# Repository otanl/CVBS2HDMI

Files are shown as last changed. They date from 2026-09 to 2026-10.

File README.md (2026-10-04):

# CVBS2HDMI — composite NTSC to HDMI on a Tang Nano 20K

English | [日本語](README.ja.md)

**v0.1**

> **Status.** What has been tested is the firmware together with the board as built, v0.1
> (tag `v0.1`). The board design now in `hardware/` is **v0.2, which has not been manufactured or
> tested**. If you make a board, either accept that, or use the v0.1 design from the tag.

CVBS2HDMI digitises composite NTSC video (CVBS) with an 8-bit ADC (AD9280), decodes it in colour on the
Tang Nano 20K's FPGA, and sends it to the on-board HDMI connector as 640×480p. There is no frame
buffer. Everything is built with an open-source toolchain (Yosys / nextpnr-himbaechel / Apicula /
openFPGALoader / Icarus Verilog); development was done on macOS.

## Features

- Colour NTSC decoding (240p and 480i) to 640×480p HDMI (DVI-compatible)
- 25.2 MSPS, one sample per clock, with no multipliers or ALU cells; the colour burst's phase
  is measured on every line with a CORDIC
- 240p, as most game consoles send it, holds still: the output frame switches between 524 and
  525 lines to match
- A broken or missing input is shown as noise, never as a black screen
- S2 zooms the picture 1.5 times and crops the border (a ring buffer of lines, no frame buffer)
- Eight glitch effects on the knobs of an M5Stack Unit 8Angle, each breaking a stage of the
  decoder itself
- Regression tests in simulation for every feature (`make test`)

Not supported: PAL, audio, black-level correction for 7.5 IRE setup.

## Hardware

- **Tang Nano 20K** (GW2AR-LV18QN88C8/I7)
- **Carrier board** (`tangADC`): an AD9280ARS and its input circuit, taking the Tang Nano 20K in
  a DIP-40 socket
  - Input: RCA → 75 Ω termination → ESD protection → 1 µF AC coupling → 20 Ω + 100 pF → AIN
  - AD9280: internal 2 V reference, single-ended input (0..2 V), clocked at 25.2 MHz by the FPGA
  - DC restoration is digital (black level measured on the front porch); the analog clamp is
    not used
  - Powered from the Tang Nano 20K's 3.3 V, with separate analog and digital rails through
    ferrite beads
- **Optional**: M5Stack Unit 8Angle (Grove J4/J5, I²C)

The carrier board's KiCad 10 project is in `hardware/`: schematic, PCB, and the JLCPCB
production files (BOM, placement, gerbers). They are at v0.2, the next revision, which has not
been manufactured; the board as built and measured is tag `v0.1`. `docs/pcb-respin.md` §4.6 and
§4.7 list the changes. Every part JLCPCB places is from its Basic or Preferred library.

Pin assignment (the single source is `constraints/tangnano20k_adc_probe.cst`):

| Signal | FPGA pin | | Signal | FPGA pin |
|---|---|---|---|---|
| `adc_clk` | 73 | | `adc_d[4]` | 29 |
| `adc_clamp` | 74 | | `adc_d[5]` | 30 |
| `adc_d[0]` | 27 | | `adc_d[6]` | 75 |
| `adc_d[1]` | 28 | | `adc_d[7]` | 77 |
| `adc_d[2]` | 72 | | `adc_otr` | 71 |
| `adc_d[3]` | 76 | | I²C SCL / SDA | 48 / 49 |

The data bus is not in physical pin order. The board's revision history, the pins that must not
be used, and the fixes planned for the next revision are in `docs/pcb-respin.md` (Japanese).

**Caution**: pin 3 of the Grove connectors is 5 V. A device that pulls I²C up to 5 V puts 5 V
on the FPGA's pins. The 8Angle pulls up to its own 3.3 V and is safe.

**Caution**: ADC bits 0, 1, 4 and 5 (pins 27..30) share an I/O bank with HDMI. Stock Apicula
packs those inputs as LVDS receivers, so every build must go through `scripts/gowin_pack_io.py`
(the Makefile does).

## Usage

### Installing the tools (once)

```sh
./scripts/setup-macos.sh
make check-tools
```

This installs the OSS CAD Suite into `.tools/oss-cad-suite`; your shell's PATH and macOS
settings are left alone.

### Building and loading

```sh
make ntsc                # build
make ntsc-program        # load into SRAM (lost at power-off)
make ntsc-flash          # write to flash (kept across power cycles)
```

`make program` loads not the HDMI decoder but the ADC probe used to bring up a board (see below).

### Buttons and LEDs

- **S1**: toggles the diagnostic view (waveform and bars). The black-and-white cells showing the
  ADC interface's state appear only at the bottom of this view.
- **S2**: toggles the 1.5× zoom, which scales up the middle of the picture and crops the border
  (for sources such as game consoles whose picture sits small inside a wide border). Both axes
  scale alike, so the aspect ratio is kept. After a switch the picture slides into place over
  about 1.5 seconds.
- **LEDs** (active low): 0 heartbeat, 1 PLL locked, 2 horizontal sync locked, 3 vertical sync
  seen, 4 and 5 the luma gain step

An input that cannot be synced (a broken signal, a wrong standard, an unplugged cable) does not
black out the screen: the signal is shown as it arrives, as noise, and a good signal is locked
again as soon as it returns. 240p (262 lines every field, 60.05 Hz), as most game consoles send
it, is shown by measuring the field length and switching the output frame between 525 and 524
lines.

### M5Stack Unit 8Angle (glitch effects)

Connect an M5Stack Unit 8Angle to Grove J4 or J5 and its eight knobs and switch are read
continuously over I²C (address 0x43, 100 kHz). Near the bottom of the S1 diagnostic view, each
knob is drawn as a cyan bar, the switch as a green block, and a red block shows while the unit
is not answering. `make sim-angle8` checks the reader against a model of the unit.

The eight knobs control **glitch effects**. They do not post-process the image; each one breaks
a stage of the decoder itself. A knob turned fully left is off, and with all knobs left the
picture is the clean one. The effects are enabled with the switch in the green position (as the
diagnostic view shows it).

Knobs 1..4 break **where lines go and their shape**, 5..8 break **colour**; each group is in the
order the signal passes through the decoder.

| Knob | What breaks |
|---|---|
| 1 | Sync slicing: dark parts of the picture read as sync, so the picture decides where lines start |
| 2 | Horizontal hold: real syncs are ignored and the line timing free-runs off frequency (sideways drift, diagonal tearing) |
| 3 | Line stretch: lines at random are stretched to twice the width or squeezed to half, leaving an older line behind |
| 4 | Line buffer: lines stop being updated, and old lines smear downwards |
| 5 | ADC bus faults: the faults this board really had, in order (pair misreads → stuck bits → crossed wiring) |
| 6 | Colour reference collapse: the burst is measured inside the picture and the oscillator drifts, so the hue jumps and rainbow stripes roll |
| 7 | Colour matrix overflow: the YUV→RGB gain is raised and the clipping removed, so bright and saturated parts fold into their complements (neon, solarised) |
| 8 | HDMI link failure: first the lanes skew, splitting red, green and blue sideways with a per-line shiver; past half way, blocks of a few lines lose a colour lane or misread it (inverted and so on). Worked out in the FPGA as the monitor would show it, so the link never drops |

`make sim-video-glitch` checks that each effect breaks the picture and that the picture is clean
again once the effect is removed. `make sim-link` checks, line by line, that the HDMI link
failure breaks the picture only in the ways it is allowed to.

### Sources with no sync step

A signal whose sync tip sits at blanking level (an early M5 setup, for example) needs a build
with different window positions. It is not switched automatically.

```sh
make ntsc-legacy
make ntsc-legacy-program
```

On a source with a sync step, the default (`LEGACY_TIMING=0`) measured 0.43% dropped rows and
colour on 120/120 frames, against 47.8% and 0/120 for `LEGACY_TIMING=1` (2026-09-24, same seed).

### Going back to a known-good version

The version verified on 2026-09-26 (tag `good-2026-09-26`) is kept as a bitstream,
`bitstreams/ntsc_good_2026-09-26.fs.gz`, so it can be written back whatever happens to the
sources or the toolchain.

```sh
make restore-flash       # write it to flash (kept across power cycles)
make restore-program     # load it into SRAM only (to try it)
git checkout good-2026-09-26   # the sources as they were
```

## Tests

```sh
make test                # everything (a few minutes)
make sim-video           # NTSC-J 75% bars, three fields, vertical interval included
make sim-zoom            # the 1.5× zoom (240p and interlaced, with a negative control)
make sim-video-glitch    # each glitch effect breaks the picture, and removing it restores it
make sim-link            # the HDMI link failure effect
make sim-hdmi            # TMDS encoding, line buffer races, start-up and video timing
```

`make test` includes negative controls: each bench also has to recognise a deliberately broken
setup as broken.

## Development and diagnostics

The decisions and measurements made during development are recorded in `CLAUDE.md`. When the
hardware behaves unexpectedly, search there first.

### Picture quality

```sh
make sim-reference       # every phase, ±100 ppm, half-wave burst, signal loss
make sim-tracking        # colour phase from the first line after 24 lines without burst
make sim-video-weak      # small sync amplitude
make sim-video-mono      # monochrome input with no burst
make sim-video-late      # recovery from a horizontal sync that arrives late
```

PNG captures of the HDMI output can be scored with the Python standard library and FFmpeg:

```sh
python3 scripts/video_quality.py 'build/cap*.png' --rows 20:350 --start 24 --bar-width 80
```

It reports, separately, rows in luma order, rows with a dark first bar, rows with colour, RGB
saturation, and row-to-row colour variation. The grey staircase in the bottom quarter is left out;
compare only captures of the same region and test pattern. The first capture after programming
is affected by the link and the vertical position re-acquiring, so always capture twice and score
the second, the same way for both sides of a comparison. Frames with no signal are counted too.
Bars in luma order do not prove that hue or amplitude is right.

With no UART, ADC values can be measured from the waveform view on HDMI:

```sh
make ntsc-scope-program             # starts in the full-range waveform and diagnostic view
# compare a phase: make ntsc-scope-program NTSC_SCOPE_PHASE=4
./scripts/live_capture.sh build/scope_new 120 8 --scope-mode 0 --phase 2
python3 scripts/scope_trace.py build/scope_new_012.png --trace-only --require-mode 0
# check the display path with a known ramp: make ntsc-scope-program NTSC_SCOPE_RAMP=2
make ntsc-program                   # back to the normal picture
```

To look at a signal that has no usable sync, capture raw ADC data without waiting for sync:

```sh
make ntsc-scope-program NTSC_SCOPE_RAMP=3 NTSC_SCOPE_FREERUN=1
./scripts/live_capture.sh build/raw_free_new 12 3 --scope-mode 3 --phase 2
python3 scripts/scope_trace.py build/raw_free_new_012.png --trace-only --require-mode 3
```

The normal capture waits for sync, and when none is found its buffer is never written, so zeros
that were never captured can be mistaken for measurements. `NTSC_SCOPE_FREERUN=1` captures every
66 ms or so regardless of sync, and the build gets its own name. `make sim-scope-freerun` checks
that all 2048 points are captured and re-captured with no sync, and that the sync-waiting mode
does not capture.

The waveform is drawn at 640×480 with three samples a pixel, and values are recovered from the
height of the red and white trace. The diagnostic build's vertical axis shows all 256 codes; to
read the S1 view of the normal build, pass `--legacy-scale` (there, codes above about 150 are
hidden behind the bars at the top). Ambiguous columns are dropped. This is an approximate
measurement from the screen, not a dump of every sample. Rows 200..207 of the diagnostic view
carry the mode, the ADC phase and a frame counter. `live_capture.sh` always captures at least
twice and checks the mode, the phase and that the counter advances; each time it sets aside the
first 120 frames as warm-up and measures the requested number after them. It never filters out
bad frames from the measured run. Each attempt is kept in its own folder and existing images are
never overwritten (use a new prefix). On the normal picture only pixel changes are checked:
without the diagnostic counter, a still picture cannot be told from a frozen capture, nor the
loaded bitstream identified. Amplitudes of oscillating parts are not validated; use
`--trace-only`, and do not use these readings to set colour gain.

### Recording the input and replaying it in simulation

The waveform view shows one sample in three; this records 32768 consecutive raw ADC samples
(about 20 lines) exactly, without the UART.

```sh
make ntsc-tape-program                                  # record once, freeze, show as grey cells
python3 scripts/live_capture.py build/tape 12 8
python3 scripts/tape_decode.py build/tape.hex build/tape_0*.png   # vote across 12 frames
python3 scripts/tape_trim.py build/tape.hex sim/my_tape.hex 18    # cut to an even number of lines
./scripts/tool iverilog -g2012 -s replay_tb -o build/replay_tb \
    src/ntsc_capture.v src/adc_front.v src/sync_lpf.v src/burst_nco.v src/cordic_atan.v \
    src/chroma_sincos.v sim/gowin_prim_sim.v sim/replay_tb.v
./scripts/tool vvp build/replay_tb +stim=sim/my_tape.hex +nsamp=<samples> +lines=400 +out=build/replay.txt
python3 scripts/replay_quality.py build/replay.txt --png build/replay.png  # same scale as the board
python3 scripts/tape_reference.py sim/my_tape.hex                          # floating-point reference decode
```

`replay_quality.py --frames 'build/cap_*.png'` scores captures from the board on the same scale.
`make sim-tape` checks the recording display and its decoder end to end against a known memory
image.

**With the M5 as the source, correctly decoded bars are not in luma order** (the M5 itself sends
yellow < cyan, green < magenta, red < blue). To evaluate with the M5, compare `replay_quality.py`'s
hue error and line-to-line variation with `tape_reference.py`'s values instead of
`video_quality.py`'s "correct rows".

## ADC probe (for bringing up a board, 27 MSPS)

A separate design for the first check on a new board: that the ADC's data is captured correctly.

Measured in step 1:

```
ADC ph=2 tog=FF min=96 max=255 thr=115 ln=1716 lmin=1715 lmax=1717 ok=15734 lns=15734 vs=60 otr=0 lk=1
```

A raw waveform (taken with `make autodump-program`, saved as `sim/ntsc_line_capture.hex`):

| Quantity | Measured | NTSC | Error |
| --- | --- | --- | --- |
| Sync tip | code 98 (±1) | — | — |
| Sync width | 4.59 us | 4.70 us | -2.3% |
| Blanking | code 133.9 | — | — |
| Sync to blanking | 282 mV | 286 mV | **-1.3%** |
| Burst start | 5.19 us after the sync edge | 5.3 us | — |
| Burst length | 2.52 us / **9.02 cycles** | 2.51 us / 9 cycles | **+0.2%** |
| Line period | **1716** samples | 1716.05 | — |

Counting exactly nine burst cycles shows that the sample clock and the subcarrier are in the right
time relation, and an amplitude error of -1.3% shows that the gain is right.

### Simulating

A synthetic NTSC signal goes through a behavioural model of the AD9280 and the line period is
measured.

```sh
make sim           # positive: must measure ln=1716
make sim-badphase  # negative: a wrong sampling phase must be reported as broken
```

The negative case exists to show that `ln=1716` is not a value that comes out whatever goes in.

### Loading it and measuring

```sh
make program   # load into SRAM (lost at power-off)
make monitor   # read the report
```

One line a second at 115200 8N1:

```
ADC ph=2 tog=FF min=79 max=205 thr=94 ln=1716 lmin=1716 lmax=1717 ok=15720 lns=15734 vs=60 otr=0
```

| Field | Meaning | Healthy value |
| --- | --- | --- |
| `ph` | sampling phase; 0..3 = 0 / 9.3 / 18.5 / 27.8 ns after the adc_clk rising edge | `2` |
| `tog` | OR of the bits that changed during the window | `FF` |
| `min` | lowest code → the sync tip level | about 70..90 |
| `max` | highest code → peak white | about 190..215 |
| `thr` | the sync slicing threshold actually used | min + a few tens |
| `ln` | the latest line period (samples) | **1716** |
| `lmin` / `lmax` | range of accepted line periods | 1716..1717 |
| `ok` | lines whose period is within 1700..1732 | about `lns` |
| `lns` | accepted lines | about 15734 |
| `vs` | vertical syncs detected | about 60 |
| `otr` | samples the AD9280 flagged as over range | `0` |

**`ln=1716` is the decisive one.** One NTSC line (15734.264 Hz) sampled at 27 MHz is

```
27e6 / 15734.264 = 1716.05 samples
```

so a steady 1716 proves at once that **the ADC clock, the data bus's bit order and the sampling
phase are all right**. No other single figure says that much.

#### Buttons (probe)

* **S2 (pin 87)**: advance the sampling phase by one. If `ln` does not appear, try all four.
* **S1 (pin 88)**: dump 2048 raw samples from a sync edge in hex, for checking the bit order by
  eye. The sync tip (a run of low values), then the back porch, then the picture should be
  visible.

#### Diagnostic LEDs (active low, probe)

| LED | Meaning |
| --- | --- |
| 0 | heartbeat (the design is running) |
| 1 | PLL locked |
| 2 | line period in range |
| 3 | vertical sync detected |
| 4 | over range detected (input too large) |
| 5 | a data bit never changes (bad wiring and so on) |

### The analog clamp is off by default

The AD9280's clamp (CLAMP/CLAMPIN) is **not used**: on this board it does more harm than good.
C2 at 1 µF is larger than the AD9280's clamp amplifier is designed for, so each pulse leaves a
transient longer than a line, which spoils the next sync edge. Measured:

| Clamp | Result |
| --- | --- |
| off (default) | `ok = lns = 15734`, `vs=60`, `ln=1716`, perfect |
| gated on sync lock | about 72% good lines, lock oscillating at 1 Hz, `vs` erratic |

Without the clamp the input still biases itself inside the conversion range (sync tip at 98,
white at about 225, 30 codes below 255). The decoder measures the porch and restores DC
digitally. The sync tip is not the black level, so do not subtract it from the picture.

`make clampgated-program` brings the clamp back for experiments.

### Builds for isolating faults

For suspecting the analog side. The RTL is the same; only a constraint or a parameter differs.

```sh
make pullup-program    # weak pull-ups on the ADC inputs; min=max=255 means the ADC is not driving the bus
make clampon-program   # CLAMP held on: AIN pinned to CLAMPIN, measurable with no video
make clampoff-program  # CLAMP held off (for comparison)
make clkhigh-program   # adc_clk held at 3.3 V → TP4 should read about 3.3 V
make clklow-program    # adc_clk held at 0 V → TP4 should read about 0 V
make clkslow-program   # adc_clk at about 1 Hz → TP4 swings 0 ↔ 3.3 V on a meter
make program           # back to normal
```

`clk=` at the end of the report shows which clock mode the loaded bitstream has.

#### The pull test: finding a floating pin without touching the board

The most effective technique of the bring-up. Build the same design three ways, with no pull,
pull-up and pull-down, and compare the reported codes in binary. **A ~50 kΩ internal pull cannot
move a pin the ADC is really driving.** A bit that follows the pull is an open joint; a bit that
resists it is connected, one pin at a time.

```sh
make program && make monitor          # no pull
make pullup-program && make monitor   # pull-up
make pulldown-program && make monitor # pull-down
```

**The trap**: a test point measures the net, not the pin. TP4 shows a healthy clock even if the
AD9280's pin 15 is lifted, and FB2 shows 3.3 V even if pin 2 is. The pull test gets round this
electrically for every pin the FPGA can read.

If `min`/`max` stay at 0 with `clampon`, the cause is not the video signal but the ADC's
conversion, its reference or the clamp circuit. If the bus does not move with `clkslow` either,
the ADC is not responding to its clock.

#### AVDD and DRVDD come from different pins

Easy to miss: the AD9280's analog and digital supplies come from **different pins of the Tang
Nano**.

```
Tang Nano DIP pad 19 → +3V3 → FB1 → +3V3A → U1 pin 28 AVDD
Tang Nano DIP pad 25 →        FB2 → +3V3D → U1 pin 2  DRVDD
```

So **a healthy TP2 (VREF) does not prove that DRVDD is there**: VREF depends on AVDD alone.
Without DRVDD the digital outputs are never driven and the bus is dead. On the v0.1 board FB1 and
FB2 are leaded parts, easy to probe at both ends. (The next revision uses 0805 chip beads; probe
TP5 and TP6 on the ADC side and the module's 3V3 pins on the other.)

## HDMI output pitfalls

**Never put `DRIVE=` or `BANK_VCCIO=` on an LVDS25 constraint.** Sipeed's `.cst` for Gowin EDA
carries `DRIVE=3.5 BANK_VCCIO=3.3`; brought into the open-source flow, it builds, meets timing,
and produces a link **no sink locks to**, with no warning. Apicula's own
`examples/tangnano20k.cst` uses only `IO_TYPE=LVDS25 PULL_MODE=NONE`.

**The 20K's HDMI pins are true LVDS.** The 9K's are emulated, so `ELVDS_OBUF`/`LVDS25E` ported
as-is is rejected outright by Apicula. Use `TLVDS_OBUF`/`LVDS25`, with P on the pair's IOBA pin
and N on its IOBB pin (33/34, 35/36, 37/38, 39/40).

**Pass the pixel clock to `--freq`.** nextpnr applies `--freq` to every clock it does not
otherwise know, so passing the serial clock (135) fails the TMDS encoder's combinational path on
a timing violation that does not exist.

### When nothing comes out, compare with a known-good bitstream

Faster than reasoning. Load Sipeed's prebuilt `.fs` (fetched with `gh`) and you know at once
whether the board, cable and sink are fine. Build Apicula's `examples/DVI` with the same flow and
you also know that the open-source toolchain can drive this board's TLVDS; what is left is the
difference from your own sources.

## Common problems

* **The report is garbled**: macOS resets a `/dev/cu.*` port to 9600 baud when its last
  descriptor closes, so `stty -f PORT 115200` followed by `cat PORT` loses the setting.
  `make monitor` (`scripts/monitor.py`) sets the speed on the descriptor it reads from.
* **The board is not found**: use a USB-C cable that carries data, and connect directly, without
  a hub.
* **`unable to open ftdi device`**: close anything using the board's USB device (a serial
  monitor, for instance) and reconnect.
* **Starting over**: `make clean`, then `make build`.

## License

MIT License. See `LICENSE`.

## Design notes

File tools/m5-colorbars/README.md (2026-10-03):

# m5-colorbars — NTSC colour bar generator for decoder calibration

Turns an M5Stack ATOM (ESP32-PICO-D4) with the RCA unit into a composite
colour bar source, so the CVBS2HDMI decoder can be checked against known values
instead of by eye.

Output is on **G26** (DAC channel 2), which is where the M5Stack RCA unit sits.
LovyanGFX's `Panel_CVBS` generates the signal; ESP32-S2/S3/C3 are not
supported by it, but the ATOM's ESP32-PICO-D4 is.

Pattern: 75% colour bars (white, yellow, cyan, green, magenta, red, blue,
black) across the top three quarters, and a 16-step grey staircase along the
bottom for checking luma gain and linearity separately from chroma.

## Build and flash

```sh
. ~/esp/esp-idf/export.sh
cd tools/m5-colorbars
idf.py set-target esp32
idf.py build
idf.py -p /dev/cu.usbserial-XXXXXXXX flash
```

The ATOM enumerates as a CH9102 bridge (`Hades2001 / M5stack` in `ioreg`), so
its port is *not* one of the Tang's two `usbserial-2025...` nodes. Pass it
explicitly — several of this project's scripts pick the last matching port and
will otherwise grab the wrong one.

## Signal type

`USE_NTSC_J` in `main/main.cpp` selects between NTSC-J (0 IRE setup, black
equals blanking) and NTSC (7.5 IRE setup). It defaults to NTSC-J because it
keeps level arithmetic simple when calibrating, and because it is what
Japanese equipment expects.

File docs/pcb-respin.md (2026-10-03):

# tangADC 基板（CVBS2HDMIのキャリア基板） 再設計 指示書

2026-09-15 時点。現行基板で見つかった問題と、次の版で必ず守る事項。

**状況（2026-10-03、v0.1）**：2章のピン変更は改版済みで、2026-09-24に実機で検証しました。
3章は、その後の実測にもとづいて書き直しています。

**次の改版（v0.2）**：3.2 と 4.1〜4.3 は 2026-10-03 に `hardware/` の設計データへ反映しました。
**まだ製造していません。** 実物があるのは v0.1 だけで、v0.1 の設計データと製造ファイルはタグ
`v0.1` にあります。`hardware/` にあるのは v0.2 の設計データと製造ファイルです。反映した内容は
4.6、製造ファイルについては 4.7 にまとめています。

---

## 1. 今回の失敗と、その本質

**ADCのデータ3本がFPGAに届いていません。** `adc_d[2]`(FPGAピン42)、
`adc_d[3]`(41)、`adc_d[6]`(31)。8ビットのうち実質24階調(256階調中)しか
使えておらず、映像の上位3バーが同じ値に潰れ、色も行ごとに揺れます。

**原因は部品でも実装でもありません。** 以下はすべて測定で除外済みです。

| 疑い | 検証方法 | 結果 |
|---|---|---|
| 半田の開放 | 配置固定のプルテスト(`scripts/scope_pull_variant.py`) | どのビットもプルに追随せず＝開放ではない |
| GNDへの短絡 | テスターで対地抵抗 | 130 kΩ、正常ビット(D5)と同値 |
| AD9280の故障 | **新品の基板＋新品のICで再現** | 同じ3ビットが死ぬ |
| 読み出し経路 | 既知の鋸波を緩衝域に書いて読み返す | 241/256値、全列が誤差1以内で線形 |
| 信号源 | スタビライザー挿入で信号を変更 | 帯状化は不変 |
| 標本化位相 | 5位相すべて | すべて同じ |
| ADCクロックのデューティ | 40% / 60% | 60%はむしろ悪化 |
| IO規格 | LVCMOS33 / 18 / 25 / 12 | すべて同一 |

**残るのはピンの選択です。** そして本質はこうです。

> **ピンが使えるかどうかを、資料を読んで判断した。実測しなかった。**

CLAUDE.md には当時から次の警告が書かれていました。

> ピン27–31 / 41 / 42 の実際のバンクVCCIOをSipeedの回路図で確認してから
> `LVCMOS33` を信用すること。入力バスのバンク電圧が違うと、**無言でデータが化ける**。

この警告を実行しなかったことが、基板一枚分の損失になりました。

---

## 2. 次の版で必ず守ること

### 2.1 ピンは発注前に実測する（最重要）

推測も資料も信用しません。**手元のTang Nanoで実際に試験します。**

```sh
# 候補ピンを pin_probe[7:0] に割り当てた .cst を作り、
# プルアップ版とプルダウン版をそれぞれ書き込んで画面のセルを読む
make ntsc            # PROBE_ON=1 でビルドしたものを使う
```

判定は単純です。

- **プルアップで1、プルダウンで0を返すピン → 自由。使える**
- **どちらかに追随しないピン → 何かが繋がっている。使わない**

死んだ3本は、まさに後者の挙動でした。理由が分からなくても、**この試験だけで
除外できます**。

さらに強い確認として、駆動して読み返す試験(`PIN_TEST=1`)もあります。
**必ず陽性対照(`PIN_TEST=2`、期待値を反転)と対で実行してください。**
比較が走っていなければ、どちらも「異常なし」に見えます。

### 2.2 ピンの第二機能（Tang Nano 20K 回路図 v1.3 より）

**この表を最初に見てください。** 今回の失敗も、次に起こりうる失敗も、ここに
書いてあります。

**設定用 — 絶対に使わない。** 電源投入時にフラッシュからビットストリームを
読むのに使われます。ADCの出力を繋ぐと起動を妨害します。

| ピン | 機能 |
|---|---|
| 5, 6, 7, 8 | TMS, TCK, TDI, TDO（JTAG。書き込みに必須） |
| 9 | RECONFIG_N |
| 52, 53 | SCLK, DOUT/WE_N |
| 54, 55, 56, 57 | DIN/CLKHOLD_N, SSPI_CS_N/D0, SO/D1, FASTRD_N/D3 |
| 59, 60, 61, 62 | MCLK/D4, MCS_N/D5, MO/D6, MI/D7 |
| 87, 88 | MODE1, MODE0（起動モード） |

**クロック / PLL — 避けるのが無難。** I/Oとしては使えますが、専用配線が
あるので他用途に取っておく価値があります。

| ピン | 機能 |
|---|---|
| 4 | LPLL1_T_in（本設計の27 MHz入力） |
| 10, 11 | GCLKT_6, GCLKC_6 |
| 13, 15, 16 | LPLL2_T_in, LPLL2_T_fb, LPLL2_C_fb |
| 35, 36 | GCLKT_4, GCLKC_4（本設計のTMDS） |
| 51, 63 | RPLL2_T_in, GCLKT_3 |
| 76, 77 | GCLKC_1, GCLKT_1 |
| 79, 80 | GCLKT_0, GCLKC_0 |

**第二機能を持たない素のI/O** — ここから選びます。

```
17 18 19 20 25 26 27 28 29 30 31 32 33 34 37 38 39 40 41 42
48 49 69 70 71 72 73 74 75 81 82 83 84 85 86
```

### 2.2.1 Tang基板上の接続と実測結果

素のI/Oでも、Tangの基板上で何かに繋がっていれば使えません。**実測が要ります。**

| ピン | Tang上の信号 | 実測 |
|---|---|---|
| 27, 28, 29, 30 | LCD_B7 / B6 / B5 / B4 | 現行で正常動作 |
| **31, 41, 42** | LCD_B3, LCD_R4, LCD_R3 | **低く固定。今回の原因** |
| **32** | LCD_G7 | **高く固定** |
| 25, 26 | LCD_HS / VS | 低く固定 / 不安定 |
| **48, 49** | LCD_DE, LCD_BL | **自由（駆動＋読み返しで確認）** |
| 17〜20 | LED0〜5 | LEDと共用 |
| 69, 70 | UART TX / RX | BL616経由のシリアル |
| 71, 73, 74 | HSPI_DIN0 / DIN2 / DIN3 | 現行で正常動作（otr / clk / clamp） |
| **72, 75** | HSPI_DIN1, HSPI_DIR | **自由** |
| 81〜86 | SDIO ほか | 固定または不安定 |

同じLCDコネクタの信号線でも一部だけが固定されています。回路図に
`LCD_INIT0`〜`LCD_INIT3` というパネル種別識別らしき信号がありますが、
**原因は未確定です。理由が分からなくても実測で除外できます。**

### 2.2.2 推奨するピン割り当て

**素のI/Oで、かつ実測で確認済みのものだけ**を使います。現行から変わるのは
データ4本だけです。

**以下が実際に製造し、2026-09-24に実機で検証した割り当てです。** 動いている
5本はそのままにして、死んでいた3本だけを動かしました。基板の改版量が最小で
済み、既知良好な配線に手を入れずに済みます。

| 信号 | 旧 | **採用** | DIPパッド | 根拠 |
|---|---|---|---|---|
| adc_d[0] | 27 | 27 | 8 | 現行で正常動作 |
| adc_d[1] | 28 | 28 | 9 | 現行で正常動作 |
| adc_d[2] | 42 ✗ | **72** | **24** | 実測で自由（HSPI_DIN1） |
| adc_d[3] | 41 ✗ | **76** | **38** | 実測で自由（GCLKC_1） |
| adc_d[4] | 29 | 29 | 12 | 現行で正常動作 |
| adc_d[5] | 30 | 30 | 13 | 現行で正常動作 |
| adc_d[6] | 31 ✗ | **75** | **3** | 実測で自由（HSPI_DIR） |
| adc_d[7] | 77 | 77 | 5 | 現行で正常動作 |
| adc_otr | 71 | 71 | 23 | 現行で正常動作 |
| adc_clk | 73 | 73 | 1 | 現行で正常動作 |
| adc_clamp | 74 | 74 | 2 | 現行で正常動作 |

**検証結果（2026-09-24、新基板＋新Tang）**: 出現する符号が 18/256 → **79/256**、
ビット2・3・6の占有率が 0.00/0.00/0.00 → **0.64/0.33/0.48**。
`y mod 16` が {12,13,14,15} に偏っていたのが全16剰余に散りました。

76番は `GCLKC_1` です。**グローバルクロック兼用ピンを普通の入力として使うのは
問題ありません**（クロック用の経路も持っているだけ）。避けなければならないのは
設定用ピンであって、クロック用ピンではありません。実測でも生きています。

**別の割り当てを採用する場合は、発注前に 2.1 の試験をもう一度通してください。**

### 2.3 パッケージに存在しないピン

QN88 に **43–47, 50, 58, 64–68, 78 は存在しません**。除外リストとして持ってください。

存在するIOピン:
```
5 6 7 8 9 10 11 13 15 16 17 18 19 20 25 26 27 28 29 30 31 32
33 34 35 36 37 38 39 40 41 42 48 49 51 52 53 54 55 56 57 59
60 61 62 63 69 70 71 72 73 74 75 76 77 79 80 81 82 83 84 85 86 87 88
```

### 2.4 使ってはいけないピン（機能が確定しているもの）

Tang Nano 20K 回路図(v1.3)より:

| ピン | 機能 | 理由 |
|---|---|---|
| 4 | SYS_CLK | 27 MHz源発振 |
| **5, 6, 7, 8** | **TMS, TCK, TDI, TDO** | **JTAG。書き込みに必須** |
| 9 | RECFG_N | 再コンフィグ |
| 15–20 | LED0–5 | オンボードLED |
| 33–40 | HDMI TMDS | 本設計で使用 |
| 69, 70 | UART TX/RX | BL616経由のシリアル |
| 80–85 | SDIO | microSD |
| 87, 88 | MODE1/0 + KEY | **起動モード。触ると起動しない** |

---

## 3. アナログ側（v0.1基板の実測にもとづく）

### 3.1 C13 は 100 pF のまま

以前ここには「820 pF〜1 nFに上げてアンチエイリアスとして機能させる」と書いていましたが、
実測で否定されました。折り返しの雑音に見えていたものは、Apiculaがビット0・1・4・5
（ピン27〜30、HDMIと同じバンク）をLVDS受信として組んでいたことが原因で、
`scripts/gowin_pack_io.py` で解決しています。

680 pFに替えた実機では、3.58 MHzの色信号が約2.5 dB落ちるだけでした（100 pFなら0.1 dB）。
LCフィルタも不要です。

### 3.2 AINの直流動作点を部品で決める（次の改版で推奨）

現状、C2より後ろ（AIN側）には直流電位を決める部品がなく、アナログクランプも使っていません。
それでも信号が変換範囲に収まっているのは、おそらくADC入力のサンプリング容量が中点への
抵抗のように働いているためです（仕組みは未確認）。入力機器やADCクロックしだいで動作点が
変わり得るので、部品で決めておきます。

- R2 を 22 kΩ → **10 kΩ** に変更し、CLAMPIN を 1.0 V（VREFの半分）にする
- AIN（TP1）と CLAMPIN（TP3）の間に **47 kΩ** を追加する

計算では、黒一色から白一色まで、どんな絵でも信号は 0.1〜1.75 V に収まります（変換範囲は
0〜2 V）。時定数は47 msで、フィールド単位のゆっくりした変動はデジタル側の黒レベル補正
（フロントポーチの測定）が吸収します。

この変更後は、アナログクランプを有効にしてはいけません。同期先端が1.0 Vに固定され、白が
2 Vで頭打ちになります。ファームは既定で無効です。変更したら、黒い画面と白い画面の両方で、
診断表示の波形の同期先端と白がコード10〜240に入っていることを確かめてください。

**v0.2での対応**：R2 を 10 kΩ にし、47 kΩ の **R19**（0603）を追加しました。R19 は R2 の右隣に
あり、AIN は TP1 へ行く裏面の配線からビア (156.85, 45.45) で取っています。47 kΩ を通る直流の
バイアスなので、AINピンから離れていても支障はありません。

この変更で CLAMPIN が 0.625 V から 1.0 V になるので、クランプを強制オンにする診断ビルド
（`make clampon-program`、`CLAMP_FORCE`）の読みも変わります。v0.1 ではコード80付近、v0.2 では
128付近が正しい値です。

### 3.3 アナログクランプは使わない

C2 が 1 µF だと、クランプの1パルスごとの過渡がライン長を超えて残ります（クランプonで
良品ライン約72%、ロックが発振）。直流再生はデジタルで十分機能しているので、クランプを
使う構成にする必要はありません。C2 は 1 µF のままで構いません。

---

## 4. 回路図とレイアウトの修正点（v0.1基板、2026-10-03のDRCより）

`hardware/` の基板に `kicad-cli pcb drc --schematic-parity` をかけた結果です。未配線は0、
回路図との不一致も0で、以下は製造は通ったものの、次の改版で直したい点です。

### 4.1 AD9280のグラウンドをGNDベタにしっかりつなぐ（優先）

U1（AD9280）の1番（AVSS）、14番（DRVSS）、16番（THREE-STATE、GNDに固定）は、F.CuのGND
ベタとはサーマルのスポーク1本でしかつながっていません（DRCの「サーマル接続不完全」）。
同じ指摘が C3（10 µF）の2番、R17の2番、J2の2番にもあります。

ただし、ベタだけが頼りなわけではありません。銅箔を調べると、これらの端子には幅0.4〜1 mmの
GND配線が別に引いてあります（1番 → C4のGND、14番 → 左へ1 mm幅、16〜18番 → C12のGND）。
弱いのは、その配線が裏面のベタへ落ちるまでの距離でした。

**v0.2での対応**：それぞれのGND配線の上、端子のすぐ横に GND ビア（0.6/0.3 mm）を1個ずつ
追加しました（(150.8, 33.5)、(140.0, 34.06)、(142.0, 44.05)）。C3の2番は、C13の跡に入れた
GNDビア（4.3）が受け持ちます。

さらに、F.Cu と B.Cu の GND ゾーンのパッド接続を「PTHのみサーマルリリーフ」にしました。
表面実装の GND パッドはベタに直結になり、DRCの「サーマル接続不完全」は6件から1件に減って
います。残る1件は J2 の2番で、スルーホールで裏面のベタにつながっているので実害はありません。

**はんだ付けの注意**：U1（AD9280）は手はんだです。GND のピン（1、14、16〜18、25番）は
ベタに直結なので熱が逃げやすくなっています。こてを少し長めに当ててください。

### 4.2 GND配線が基板端に近すぎる

F.Cu の GND 配線3本（長さ 2.4 mm、2.4 mm、29.6 mm）が、基板端から0.22 mmしか離れていません
（設定は0.5 mm）。内側へ寄せてください。

**v0.2での対応**：幅を1 mmから0.5 mmにして y = 27.0 mm へ移しました。基板端から0.69 mm、
Tang Nanoのパッドから0.25 mmです（端とパッドの間は0.9 mmほどしかないので、1 mm幅のままでは
入りません）。

### 4.3 C13 が Tang Nano のフットプリントの下にある

C13（100 pF、リード部品の円板コンデンサ）がU2（Tang Nano 20K）のコートヤード内にあります。
今の基板ではソケットの高さで逃げていますが、0603のチップ部品にしてAINピンの近くに置けば、
干渉もなくなり、配線も短くなります。値は100 pFのままです（3.1）。

**v0.2での対応**：0603（`C_0603_1608Metric_Pad1.08x0.95mm_HandSolder`、他のコンデンサと同じ）に
替えました。位置は元と同じ、R3とR2の間です。U1の27番のすぐ下は基準電圧のコンデンサ（C6ほか）で
埋まっていて、これ以上は寄せられませんでした。既存のAINとGNDの配線は、そのまま新しいパッドに
届いています。

元のリード部品の穴は、表と裏の配線をつなぐ役も兼ねていました（AINはTP1へ行く裏面の配線、GNDは
C1・C3から来る表の配線と裏のGND）。これはビア2個で置き換えています：AIN (153.35, 46.2)、
GND (153.678, 42.0)。

### 4.4 回路図シンボルの誤記

U2のピン13（FPGA 30番、D5）の名前が「30_IOB14A」になっています。正しくは「30_IOB14B」です
（29番と30番でペア）。電気的には問題ありません。

### 4.5 フットプリントライブラリを同梱する

J3（`RJ-2410N`）と U2（`0my_project`）のフットプリントライブラリがプロジェクトに含まれて
いません。フットプリント自体はPCBファイルに埋め込まれているので開いて編集はできますが、
ライブラリから更新しようとすると失敗します。他の人が編集できるよう、`hardware/` に
ライブラリとプロジェクト用の `fp-lib-table` を入れてください。

コートヤードの重なり（37件）とシルクの重なりは見た目だけの指摘なので、残っていて構いません。

4.4 と 4.5 は v0.2 でも未対応です。`0my_project` は nosuz/kicad-symbols-footprints（GitHub）、
`RJ-2410N` は SamacSys の配布物で、どちらも第三者のものです。公開リポジトリに同梱してよいかを
先に確かめる必要があります。4.4 の誤記は、その上流のライブラリ自体にあります。

### 4.6 v0.2 の設計データに入れた変更（2026-10-03、未製造）

| 項目 | v0.1 | v0.2 |
|---|---|---|
| R2 | 22 kΩ | **10 kΩ**（LCSC C25804、R4などと同じ） |
| R19 | なし | **47 kΩ 0603**（LCSC C25819）、AIN と CLAMPIN の間 |
| C13 | 100 pF リード部品 | **100 pF 0603 C0G**（LCSC C14858） |
| FB1, FB2 | リード付きビーズ（抵抗用のフットプリントを流用） | **0805 チップビーズ 600 Ω@100 MHz**（Sunlord GZ2012D601TF、LCSC C1017、Basic） |
| C7 | 1 µF タンタル（C7174、Extended） | **1 µF 50 V X7R セラミック 1206**（C1848、Basic）。フットプリントはそのまま |
| D1 | PESD5V0U1BA、SOD-323（C5199862、Extended） | **H5VL10B、DFN1006-2L**（C7420372、Preferred）。フットプリントは `D_SOD-882` |
| CLAMPIN | 0.625 V | 1.0 V |
| GNDビア | — | U1 の1番・14番・16〜18番の横に各1個、C13の跡に1個 |
| 上端のGND配線 | 幅1 mm、端から0.22 mm | 幅0.5 mm、端から0.69 mm |
| 回路図の未接続フラグ | 72・75・76番に残り、31・41・42番に無し | 実際の接続どおりに付け直し |
| シルク（表面） | 基板名・版数なし | 「tangADC v0.2」「Grove:5V」（J2の下）、J1 の「GND」「IN」、テストポイントの対応表（Tang Nano の下） |

**フェライトビーズについて。** v0.1 のリード付きビーズは、下を横切る配線をまたぐジャンパの役も
兼ねていました（FB1 は表のGND配線と裏のGND・AIN配線、FB2 は表のGND配線と裏のCLAMPIN・CLK配線）。
チップ部品ではそれができないので、次のようにしています。

- **FB1** は (160.65, 43.99) に置き、TP7 から U2 の20番へ行く表のGND配線をパッドの間に通して
  います。その配線は、通る部分と斜めの部分だけ幅を 1 mm から 0.6 mm にしました（パッドとの間隔を
  取るため）。+3V3 は元の下側の穴の位置のビアで表へ上げ、+3V3a は元の上側の穴の位置のビアで
  表と裏をつないでいます。取り付け穴 H2 のネジ頭の範囲（半径2.95 mm）には入っていません。
- **FB2** は (159.56, 34.34) に置き、表のGND配線の南側に収めました。Tang Nano の3V3（25番）から
  来る裏の配線は、GND配線の下をくぐってからビア (158.4, 33.4) で表へ上げています。

AD9280 の消費は30 mA台で、このビーズは500 mA・0.3 Ωなので余裕があります。

**シルクについて。** v0.1 と v0.2 は CLAMPIN の電圧が違うので、基板を見て区別できるよう版数を
入れました。テストポイントの対応表は Tang Nano の下にあるので、モジュールを抜いたときにだけ
見えます。裏面に入れるのが理想ですが、Konnect では裏面用の鏡文字が作れませんでした。裏面に
移したいときは、KiCad で文字を選んで裏返してください。部品番号の文字がパッドや他の線に
重なっている箇所（DRCのシルク警告）は、そのままです。

確認結果（`kicad-cli pcb drc --schematic-parity`）：未配線 0、回路図との不一致 0、クリアランス
違反 0、基板端クリアランス違反 0（3件から）、コートヤード内のスルーホール 0（2件から）、
サーマル接続不完全 1（6件から、4.1）。残るのはコートヤードの重なり38件（R19の分が1件増）と
シルクの警告です。
ERC は14件から6件になり、残りはすべて電源フラグ（PWR_FLAG）が無いことによるものです。

### 4.7 製造ファイル（v0.2、2026-10-03）

`hardware/jlcpcb/production_files/` の BOM・部品配置・ガーバーは v0.2 のものに作り直して
あります（v0.1 のものはタグ `v0.1` にあります）。

**JLCPCBに実装してもらう13種類の部品は、Basic 12種類と Preferred 1種類で、Extended は
ありません。** Preferred は Basic と同じく、Extended の手数料がかからない区分です。v0.1 では
C7 と D1 の2種類が Extended でした。

- **C7** は、タンタルと同じ 3216 サイズのセラミックに替えました。パッドはタンタル用のままで
  載ります。VREF には別に 0.1 µF（C6）が付いているので、セラミックで問題ありません。シルクの
  極性マークは残っていますが、無極性なので向きは問いません。
- **D1** は、SOD-323 に手数料なしの双方向品がなかったので、小さいパッケージに替えました。
  双方向・5 V という性質は同じで、容量は 15 pF です（映像の帯域には影響しません）。片方向の
  保護ダイオードは使えません。信号が 0 V より下に振れる入力機器で、同期の先端を削るからです。
- 手はんだで付けるのは、U1（AD9280）、U2 のソケット、コネクタ、テストポイントです。AD9280 は
  JLCPCB では Extended（在庫も少ない）なので、BOM には入れていません。

**作り方。** ガーバーとドリルは `kicad-cli` で出しています。

```sh
kicad-cli pcb export gerbers -l F.Cu,B.Cu,F.Paste,B.Paste,F.SilkS,B.SilkS,F.Mask,B.Mask,Edge.Cuts \
    --no-protel-ext --subtract-soldermask -o OUT/ hardware/tangADC.kicad_pcb
kicad-cli pcb export drill --format excellon --drill-origin absolute --excellon-units in \
    --excellon-zeros-format decimal --excellon-separate-th --generate-map --map-format pdf \
    -o OUT/ hardware/tangADC.kicad_pcb
```

ファイル名は、これまで使っていた JLCPCB 用プラグインの名前（`CuTop`、`MaskTop` など）に
合わせています。この方法で v0.1 の基板から作り直すと、9層のうち7層とドリル2つが、実際に
発注したファイルと日付以外は完全に一致しました。残りの2層の違いは、裏面の銅のベタの頂点が
1つ違うことと、表のレジストに取り付け穴4か所の開口があるかどうかで、どちらも仕上がりには
影響しません。

BOM と部品配置（CPL）もプラグインと同じ書式です。回転角は、変更していない部品については
v0.1 の値をそのまま引き継いでいます。プラグインの記録（`hardware/jlcpcb/project.db`）も
同じ部品番号に更新してあるので、今後プラグインで作り直しても同じ結果になります。

発注画面では、部品の向きのプレビューを必ず確認してください。特に D1 は新しいパッケージです。

---

## 5. 発注前チェックリスト

- [ ] 全信号のピン番号を **2.4 の禁止リスト**と突き合わせた
- [ ] 全信号のピン番号が **2.3 の存在リスト**に入っている
- [ ] ADCデータ8本すべてを **2.1 の実測試験**に通した（陽性対照つき）
- [x] C13 は 100 pF（3.1）
- [x] AIN に直流の経路がある（3.2）— R19、v0.2 の設計データで対応
- [x] U1 の GND 端子がベタに直接つながっている（4.1）— GNDビアを追加し、ゾーンのパッド接続も変更済み
- [x] DRC の基板端クリアランス違反が0（4.2）
- [x] 製造ファイル（BOM・配置・ガーバー）を v0.2 で作り直した（4.7）
- [ ] 発注画面で部品の向きのプレビューを確認した（4.7）
- [ ] Tang Nano 20K 回路図 v1.3 を手元に置いて確認した

---

## 6. 参考

- Tang Nano 20K 回路図 v1.3
  https://iot-kmutnb.github.io/blogs/fpga/tang_nano_boards/tang_nano_20k_schematic_v1.3.pdf
- GW2AR シリーズ パッケージ＆ピンアウト UG229E
  https://cdn.gowinsemi.com.cn/UG229E.pdf
- Apicula の配置依存誤動作(GW2A-18C、未解決)
  https://github.com/YosysHQ/apicula/issues/541

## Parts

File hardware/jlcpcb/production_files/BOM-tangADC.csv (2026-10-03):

Comment | Designator | Footprint | LCSC | Quantity
0.1u | C1,C10,C11,C12,C4,C6,C8 | C_0603_1608Metric_Pad1.08x0.95mm_HandSolder | C14663 | 7
100p | C13 | C_0603_1608Metric_Pad1.08x0.95mm_HandSolder | C14858 | 1
10k | R14,R17,R2,R4 | R_0603_1608Metric | C25804 | 4
10u | C3,C5,C9 | C_0805_2012Metric_Pad1.18x1.45mm_HandSolder | C15850 | 3
1u | C7 | CP_EIA-3216-10_Kemet-I_HandSolder | C1848 | 1
1u | C2 | C_0805_2012Metric_Pad1.18x1.45mm_HandSolder | C28323 | 1
20 | R10,R11,R12,R18,R3,R5,R6,R7,R8,R9 | R_0603_1608Metric | C22950 | 10
33 | R13 | R_0603_1608Metric | C23140 | 1
4.7k | R15,R16 | R_0603_1608Metric | C23162 | 2
47k | R19 | R_0603_1608Metric | C25819 | 1
600R@100MHz | FB1,FB2 | L_0805_2012Metric | C1017 | 2
75 | R1 | R_0603_1608Metric | C4275 | 1
H5VL10B | D1 | D_SOD-882 | C7420372 | 1
Tang_Nano_20K | U2 | DIP-40_TangNano20K |  | 1
Conn_01x04_Pin | J4 | NS-Tech_Grove_1x04_P2mm_Vertical |  | 1
Conn_01x04_Pin | J5 | NS-Tech_Grove_1x04_P2mm_Vertical |  | 1
RJ-2410N | J3 | RJ2410N |  | 1
TestPoint | TP7 | TestPoint_THTPad_D1.0mm_Drill0.5mm |  | 1
TestPoint | TP6 | TestPoint_THTPad_D1.0mm_Drill0.5mm |  | 1
TestPoint | TP1 | TestPoint_THTPad_D1.0mm_Drill0.5mm |  | 1
TestPoint | TP5 | TestPoint_THTPad_D1.0mm_Drill0.5mm |  | 1
TestPoint | TP4 | TestPoint_THTPad_D1.0mm_Drill0.5mm |  | 1
TestPoint | TP3 | TestPoint_THTPad_D1.0mm_Drill0.5mm |  | 1
TestPoint | TP2 | TestPoint_THTPad_D1.0mm_Drill0.5mm |  | 1
AD9280ARS | U1 | SSOP-28_5.3x10.2mm_P0.65mm |  | 1
screw | J1 | Altech_AK100_1x02_P5.00mm |  | 1
Conn_01x12_Pin | J2 | PinHeader_2x06_P2.54mm_Vertical |  | 1

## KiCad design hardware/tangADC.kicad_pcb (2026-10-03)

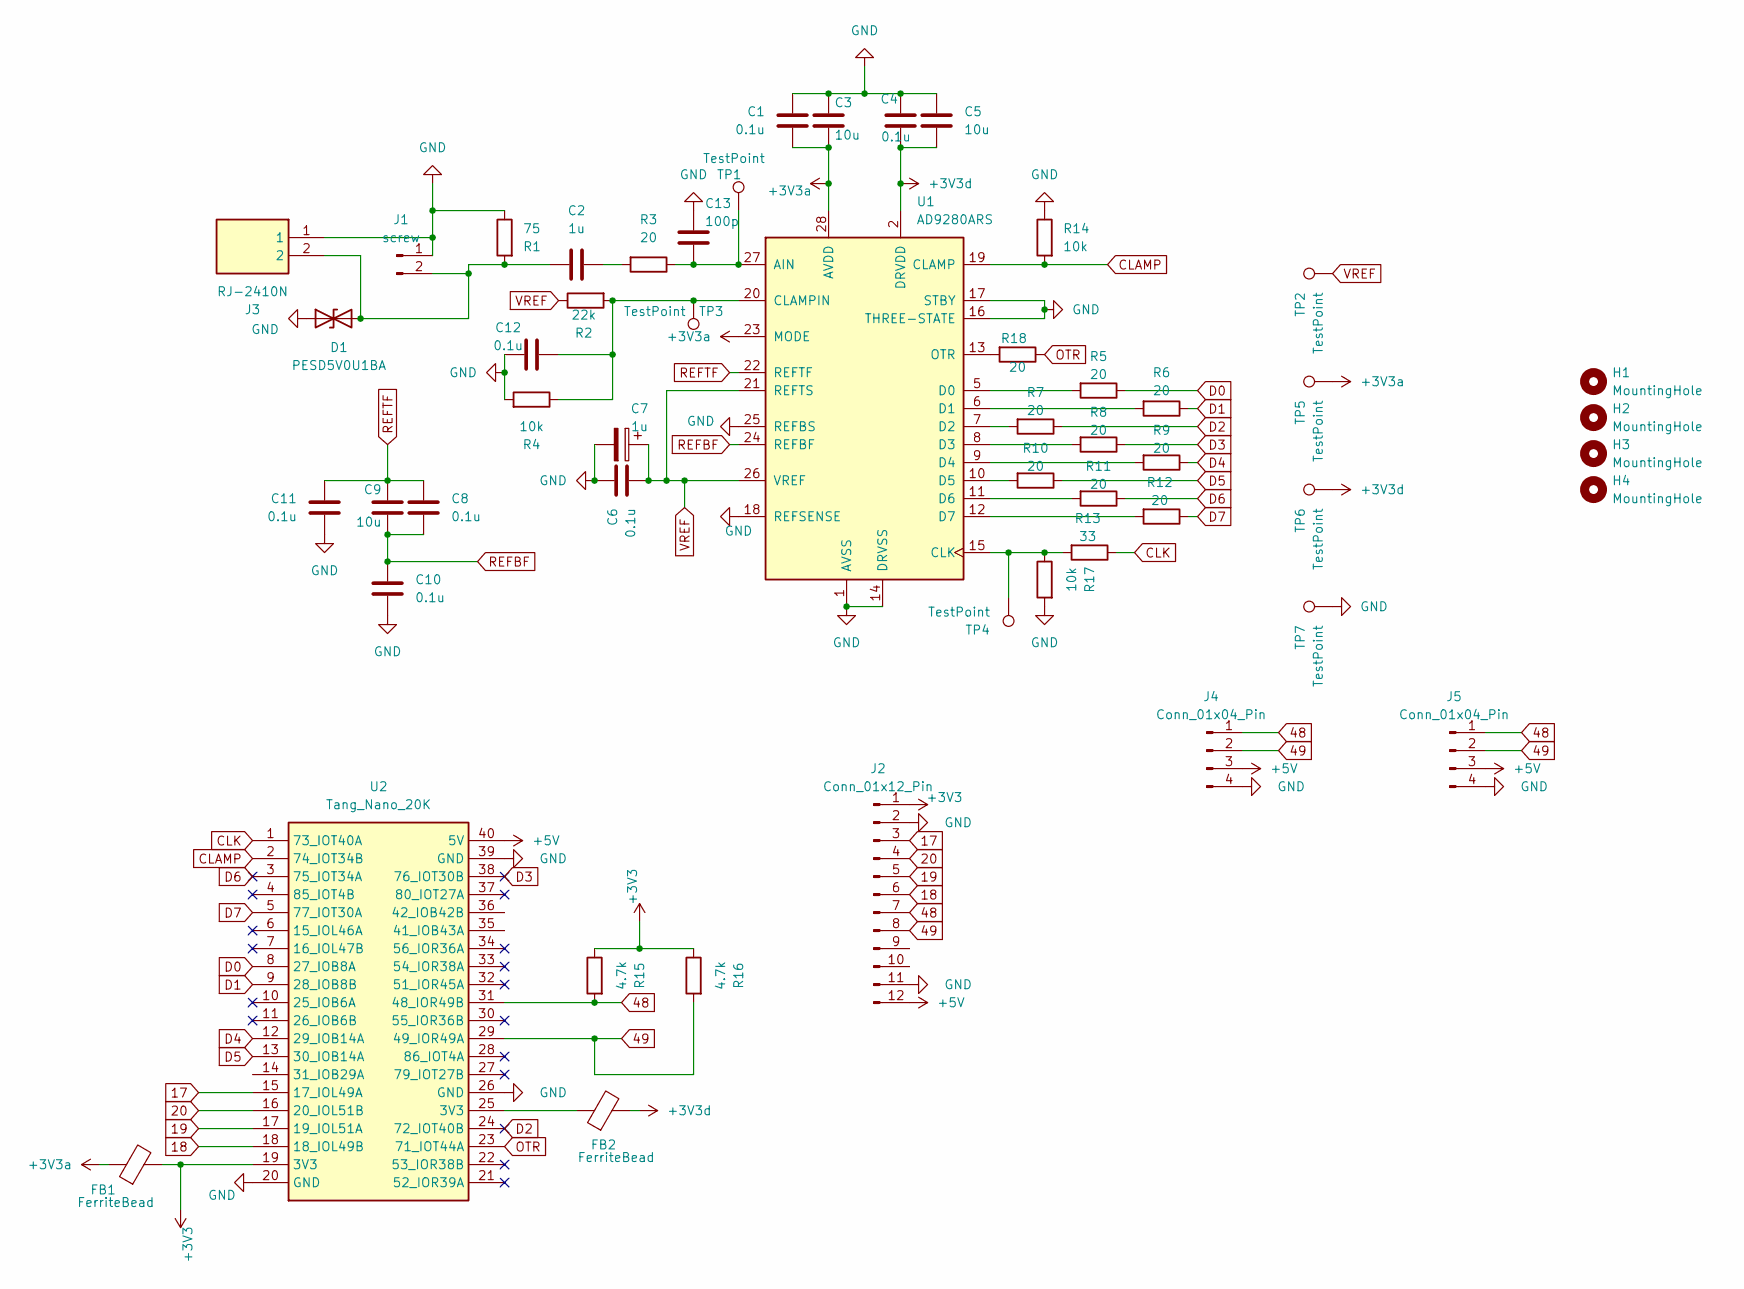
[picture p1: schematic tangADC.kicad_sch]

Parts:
C1, C4, C6, C8, C10, C11, C12: 0.1u; C_0603_1608Metric_Pad1.08x0.95mm_HandSolder
C2: 1u; C_0805_2012Metric_Pad1.18x1.45mm_HandSolder
C3, C5, C9: 10u; C_0805_2012Metric_Pad1.18x1.45mm_HandSolder
C7: 1u; CP_EIA-3216-10_Kemet-I_HandSolder
C13: 100p; C_Disc_D3.0mm_W2.0mm_P2.50mm
D1: PESD5V0U1BA; D_SOD-323
FB1, FB2: FerriteBead; R_Axial_DIN0204_L3.6mm_D1.6mm_P5.08mm_Horizontal
H1, H2, H3, H4: MountingHole; MountingHole_2.7mm_M2.5
J1: screw; Altech_AK100_1x02_P5.00mm
J2: Conn_01x12_Pin; PinHeader_2x06_P2.54mm_Vertical
J3: RJ-2410N; RJ2410N; Manufacturer_Part_Number RJ-2410N
J4, J5: Conn_01x04_Pin; NS-Tech_Grove_1x04_P2mm_Vertical
R1: 75; R_0603_1608Metric
R2: 22k; R_0603_1608Metric
R3, R5, R6, R7, R8, R9, R10, R11, R12, R18: 20; R_0603_1608Metric
R4, R14, R17: 10k; R_0603_1608Metric
R13: 33; R_0603_1608Metric
R15, R16: 4.7k; R_0603_1608Metric
TP1, TP2, TP3, TP4, TP5, TP6, TP7: TestPoint; TestPoint_THTPad_D1.0mm_Drill0.5mm
U1: AD9280ARS; SSOP-28_5.3x10.2mm_P0.65mm
U2: Tang_Nano_20K; DIP-40_TangNano20K

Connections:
17: J2.3, U2.15 (17_IOL49A)
18: J2.6, U2.18 (18_IOL49B)
19: J2.5, U2.17 (19_IOL51A)
20: J2.4, U2.16 (20_IOL51B)
48: J2.7, J4.1, J5.1, R15.2, U2.31 (48_IOR49B)
49: J2.8, J4.2, J5.2, R16.2, U2.29 (49_IOR49A)
+3V3: FB1.2, J2.1, R15.1, R16.1, U2.19 (3V3)
+3V3a: C1.1, C3.1, FB1.1, TP5.1 (1_1), U1.23 (MODE), U1.28 (AVDD)
+3V3d: C4.1, C5.1, FB2.2, TP6.1 (1_1), U1.2 (DRVDD)
+5V: J2.12, J4.3, J5.3, U2.40 (5V)
CLAMP: R14.2, U1.19 (CLAMP), U2.2 (74_IOT34B)
CLK: R13.1, U2.1 (73_IOT40A)
D0: R5.1, U2.8 (27_IOB8A)
D1: R6.1, U2.9 (28_IOB8B)
D2: R7.1, U2.24 (72_IOT40B)
D3: R8.1, U2.38 (76_IOT30B)
D4: R9.1, U2.12 (29_IOB14A)
D5: R10.1, U2.13 (30_IOB14A)
D6: R11.1, U2.3 (75_IOT34A)
D7: R12.1, U2.5 (77_IOT30A)
GND: C1.2, C3.2, C4.2, C5.2, C6.2, C7.2, C10.1, C11.1, C12.2, C13.2, D1.1 (A1), J1.1, J2.2, J2.11, J3.1, J4.4, J5.4, R1.1, R4.2, R14.1, R17.2, TP7.1 (1_1), U1.1 (AVSS), U1.14 (DRVSS), U1.16 (THREE-STATE), U1.17 (STBY), U1.18 (REFSENSE), U1.25 (REFBS), U2.20 (GND), U2.26 (GND), U2.39 (GND)
unnamed: C2.2, R3.2
unnamed: C2.1, D1.2 (A2), J1.2, J3.2, R1.2
unnamed: FB2.1, U2.25 (3V3)
unnamed 24: C13.1, R3.1, TP1.1 (1_1), U1.27 (AIN); also elsewhere on the board
unnamed 25: C12.1, R2.2, R4.1, TP3.1 (1_1), U1.20 (CLAMPIN); also elsewhere on the board
unnamed: R13.2, R17.1, TP4.1 (1_1), U1.15 (CLK)
unnamed: R5.2, U1.5 (D0)
unnamed: R6.2, U1.6 (D1)
unnamed: R7.2, U1.7 (D2)
unnamed: R8.2, U1.8 (D3)
unnamed: R9.2, U1.9 (D4)
unnamed: R10.2, U1.10 (D5)
unnamed: R11.2, U1.11 (D6)
unnamed: R12.2, U1.12 (D7)
unnamed: R18.2, U1.13 (OTR)
OTR: R18.1, U2.23 (71_IOT44A)
REFBF: C8.1, C9.1, C10.2, U1.24 (REFBF)
REFTF: C8.2, C9.2, C11.2, U1.22 (REFTF)
VREF: C6.1, C7.1, R2.1, TP2.1 (1_1), U1.21 (REFTS), U1.26 (VREF)

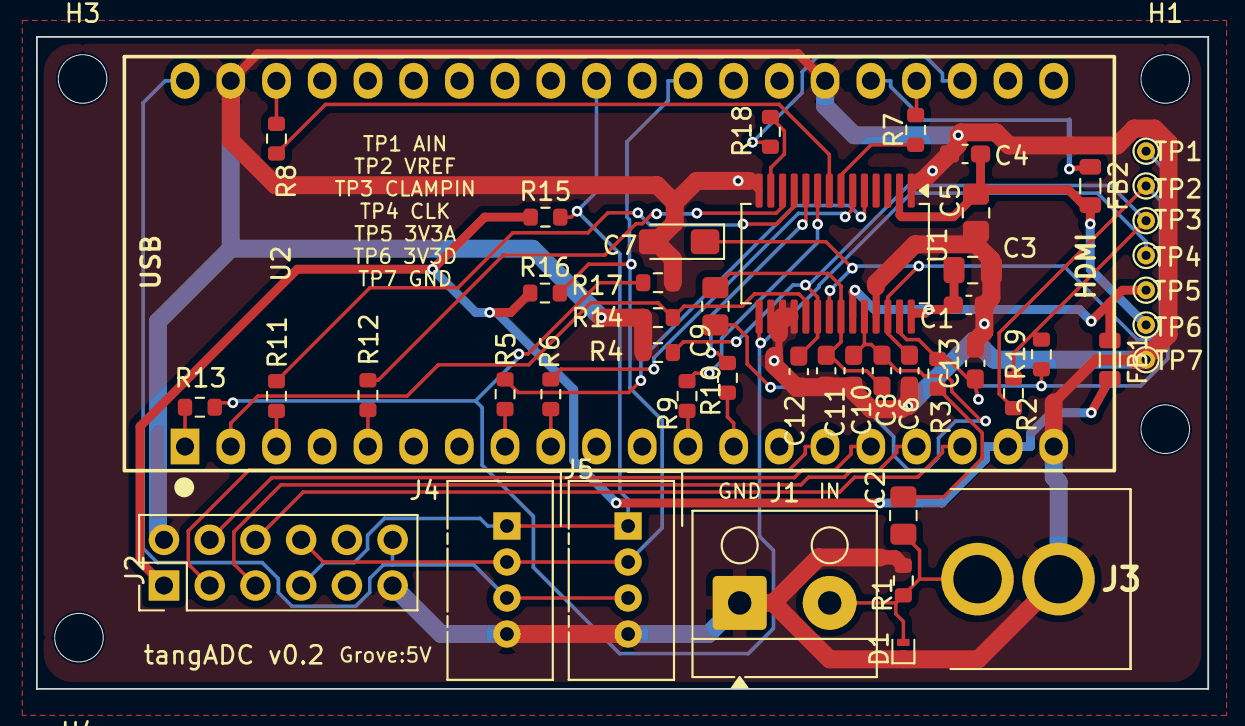
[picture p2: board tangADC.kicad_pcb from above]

Board: 2 copper layers, 65.1 x 36.2 mm, 53 parts (0 on the bottom side), 40 nets.

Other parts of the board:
R19: 47k; R_0603_1608Metric

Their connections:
unnamed 24: R19.1; also elsewhere on the board
unnamed 25: R19.2; also elsewhere on the board

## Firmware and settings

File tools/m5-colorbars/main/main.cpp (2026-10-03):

// SMPTE-style colour bars out of an M5Stack ATOM (ESP32-PICO-D4) as NTSC
// composite, for calibrating the CVBS2HDMI decoder.
//
// Why this exists: a decoder cannot be validated against a picture whose
// correct answer is unknown.  These bars have exact, published YUV values, so
// the FPGA's demodulated output can be checked numerically instead of by eye.
//
// Panel_CVBS drives the signal from the ESP32 DAC; the M5Stack RCA unit is on
// G26 (DAC channel 2).  It comes from M5GFX rather than LovyanGFX directly --
// same code, but LovyanGFX is not published to the ESP component registry
// while M5GFX is, so this builds with plain `idf.py` and no vendored source.

#include <M5GFX.h>
#include "freertos/FreeRTOS.h"
#include "freertos/task.h"
#include "esp_heap_caps.h"
#include "esp_log.h"

// NTSC has a 7.5 IRE setup pedestal, NTSC-J has none (black == blanking).
// NTSC-J keeps the arithmetic honest when checking levels, and is what
// Japanese equipment expects.  Set to 0 for plain NTSC.
#define USE_NTSC_J 1

// Overridable from the build so the level can be swept against a real
// measurement of the sync fraction rather than guessed:
//   idf.py build -DM5_OUTPUT_LEVEL=192
// Render a mostly-black frame instead of the bars.  Not a picture anyone
// wants -- it is a test for whether the capture side's black level depends on
// how bright the picture is, which it will if the input is AC coupled with no
// DC restoration.  A bright picture then pushes sync and blanking towards the
// bottom of the ADC range and clips them, and that is a property of the
// coupling, not of the generator.
//   idf.py build -DM5_DARK=1
#ifndef M5_DARK
#define M5_DARK 0
#endif

#ifndef M5_OUTPUT_LEVEL
#define M5_OUTPUT_LEVEL 128
#endif

// 720x480 is the panel maximum but needs 345 kB; an ATOM has no PSRAM.
// 360x240 is an exact half in both axes, so pixels stay square.
static constexpr int MEM_W = 360;
static constexpr int MEM_H = 240;

class LGFX : public m5gfx::LGFX_Device {
public:
    m5gfx::Panel_CVBS _panel;

    LGFX(void) {
        {
            auto cfg = _panel.config();
            cfg.memory_width  = MEM_W;
            cfg.memory_height = MEM_H;
            cfg.panel_width   = MEM_W;
            cfg.panel_height  = MEM_H;
            cfg.offset_x      = 0;
            cfg.offset_y      = 0;
            _panel.config(cfg);
        }
        {
            auto cfg = _panel.config_detail();
#if USE_NTSC_J
            cfg.signal_type = cfg.signal_type_t::NTSC_J;
#else
            cfg.signal_type = cfg.signal_type_t::NTSC;
#endif
            cfg.pin_dac      = 26;     // M5Stack RCA unit
            cfg.use_psram    = 0;      // ATOM has none
            // Raised above the library default of 128, deliberately.
            //
            // Panel_CVBS emits sync at DAC code 0 and everything else relative
            // to it: blanking at 286 mV, white at 960 mV, so 29.8% of the
            // signal is sync, exactly as NTSC asks.  The ESP32's DAC does not
            // deliver that.  Measured through the CVBS2HDMI front end, a DAC
            // code near the bottom is worth 0.65 ADC codes while one in the
            // middle is worth 1.75 -- the bottom of the DAC's range is
            // compressed about 2.7:1 -- so the sync pulse arrives at 17 ADC
            // codes where it should be 38, and the sync fraction is 13%
            // instead of 29%.  The pulse is flat, so this is the DAC's
            // transfer curve and not a coupling capacitor drooping.
            //
            // output_level scales blanking, black and white away from a sync
            // that stays pinned at code 0, which lifts them clear of the
            // compressed region and restores some of the ratio.  It costs
            // total amplitude: the signal is no longer 1 Vpp, which matters if
            // this generator is ever fed to something expecting a standard
            // level.  See M5_OUTPUT_LEVEL below for the measured sweep.
            cfg.output_level = M5_OUTPUT_LEVEL;
            // Left at the library default.  Three separate attempts to
            // "correct" the M5 side from capture-side numbers were all wrong,
            // every one of them founded on min/max over a whole second -- an
            // extreme-value statistic that a single clamp transient pins to
            // the rails.  Judge amplitude from the waveform, never from those.
            cfg.chroma_level = 128;
            _panel.config_detail(cfg);
        }
        setPanel(&_panel);
    }
};

static LGFX gfx;

// 75% colour bars: every primary is either 0 or 191.  Order is the standard
// descending-luminance one, so a correctly decoded picture has a monotonic
// luma staircase left to right.
struct Bar { uint8_t r, g, b; const char *name; };
static const Bar BARS[8] = {
    {191, 191, 191, "white75"},
    {191, 191,   0, "yellow" },
    {  0, 191, 191, "cyan"   },
    {  0, 191,   0, "green"  },
    {191,   0, 191, "magenta"},
    {191,   0,   0, "red"    },
    {  0,   0, 191, "blue"   },
    {  0,   0,   0, "black"  },
};

static const char *TAG = "colorbars";

extern "C" void app_main(void)
{
    // rgb332 rather than rgb565: the frame buffer lives in SRAM (an ATOM has
    // no PSRAM) and 360x240 costs 86 kB at one byte per pixel against 173 kB
    // at two.  The larger one does not reliably fit alongside the rest of the
    // system, and a failed init produces a dead or garbage signal rather than
    // an obvious error.  256 colours is ample for colour bars.
    ESP_LOGI(TAG, "free heap before init: %u", (unsigned)esp_get_free_heap_size());
    ESP_LOGI(TAG, "largest free block   : %u",
             (unsigned)heap_caps_get_largest_free_block(MALLOC_CAP_8BIT));

    gfx.setColorDepth(m5gfx::color_depth_t::rgb332_1Byte);
    bool ok = gfx.init();

    ESP_LOGI(TAG, "init %s, panel %dx%d, free heap now %u",
             ok ? "OK" : "FAILED", gfx.width(), gfx.height(),
             (unsigned)esp_get_free_heap_size());
    if (!ok) {
        ESP_LOGE(TAG, "Panel_CVBS init failed - no signal will be generated");
    }

    const int w = gfx.width();
    const int h = gfx.height();

#if M5_DARK
    gfx.fillScreen(gfx.color888(0, 0, 0));
    gfx.fillRect(0, 0, w / 16, h / 8, gfx.color888(191, 191, 191));
    ESP_LOGI(TAG, "dark test pattern");
#else
    // Top three quarters: the colour bars themselves.
    const int bars_h = (h * 3) / 4;
    for (int i = 0; i < 8; ++i) {
        int x0 = (w * i) / 8;
        int x1 = (w * (i + 1)) / 8;
        gfx.fillRect(x0, 0, x1 - x0, bars_h,
                     gfx.color888(BARS[i].r, BARS[i].g, BARS[i].b));
    }

    // Bottom quarter: a grey staircase, for checking luma gain and linearity
    // independently of any chroma decoding.
    const int ramp_y = bars_h;
    const int ramp_h = h - bars_h;
    for (int i = 0; i < 16; ++i) {
        int x0 = (w * i) / 16;
        int x1 = (w * (i + 1)) / 16;
        int v  = i * 255 / 15;
        gfx.fillRect(x0, ramp_y, x1 - x0, ramp_h, gfx.color888(v, v, v));
    }

    ESP_LOGI(TAG, "colour bars drawn: 8 bars over %d rows, ramp over %d rows",
             bars_h, ramp_h);
#endif  // M5_DARK

    while (true) {
        vTaskDelay(pdMS_TO_TICKS(5000));
        ESP_LOGI(TAG, "alive, free heap %u", (unsigned)esp_get_free_heap_size());
    }
}

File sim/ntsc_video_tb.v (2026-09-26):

`default_nettype none
`timescale 1ns/1ps

// Independent NTSC-J encoder: 227.5 carrier cycles/line, 262.5 lines/field,
// 4.7 us sync, nine-cycle -U burst, 75% RGB bars. Values are not derived
// from the DUT's timing windows or colour coefficients.
module ntsc_video_tb;
    parameter integer SYNC_DEPTH = 36;
    parameter integer MONO = 0;
    parameter integer FIELDS = 3;
    parameter integer VBI_LINES = 24;
    parameter integer HSHIFT = 0;
    parameter integer TOD_NS = 10;      // converter output delay after adc_clk
    // Glitch effects (ntsc_capture's fx) applied from sample FX_FROM to FX_TO.
    // Nothing is checked from FX_FROM until RECOVER samples after FX_TO, and
    // then the picture must be exactly as good as without them.  Meanwhile the
    // effect must show: FX_MIN_BAD wrong colour channels at least, or at most
    // FX_MAX_LINES lines published.
    parameter [63:0]  FX = 64'd0;
    parameter integer FX_FROM = 0;
    parameter integer FX_TO = 0;
    parameter integer RECOVER = 1602*200;
    parameter integer FX_MIN_BAD = 0;
    parameter integer FX_MAX_LINES = 1000000;
    // 126 MHz and the pixel clock divided from it, as on the board; the
    // decoder runs on the pixel clock, one sample per clock.
    reg fclk = 0;
    always #3.968 fclk = ~fclk;
    wire clk;
    CLKDIV #(.DIV_MODE("5")) u_div (.CLKOUT(clk), .HCLKIN(fclk), .RESETN(1'b1), .CALIB(1'b0));
    reg rst_n = 0;
    reg [7:0] adc = 100;
    wire adc_clk, wr_en, line_done, vsync_pulse, locked;
    wire [10:0] wr_addr;
    wire [23:0] rgb;
    wire [7:0] black;
    integer n = 0;
    wire glitching  = (FX != 64'd0) && (n >= FX_FROM) && (n < FX_TO);
    wire recovering = (FX != 64'd0) && (n >= FX_FROM) && (n < FX_TO + RECOVER);
    integer glitch_bad = 0, glitch_lines = 0;
    ntsc_capture #(.ADC_WIN_W(10)) dut (
        .clk(clk), .fclk(fclk), .rst_n(rst_n), .adc_d(adc), .adc_otr(1'b0),
        .adc_clk(adc_clk), .adc_clamp(), .rot_sel(4'd0), .fx(glitching ? FX : 64'd0), .gain_sel(2'd0),
        .wr_en(wr_en), .wr_addr(wr_addr), .wr_data(rgb), .wr_bank(),
        .line_done(line_done), .vsync_pulse(vsync_pulse), .sync_locked(locked),
        .black_out(black), .dmp_ack(1'b0)
    );
    integer stim_n, pos, fsamp, half_no, half_pos, bar, r, g, b;
    integer lines = 0, pixels = 0, fields = 0, checks = 0, bad_lines = 0;
    integer bad_colours = 0, er, eg, eb, err, max_error = 0;
    real phase, value, yy, uu, vv;
    localparam real PI = 3.141592653589793;
    task bar_rgb(input integer idx, output integer rr, gg, bb);
        begin
            rr = (idx == 0 || idx == 1 || idx == 4 || idx == 5) ? 191 : 0;
            gg = (idx == 0 || idx == 1 || idx == 2 || idx == 3) ? 191 : 0;
            bb = (idx == 0 || idx == 2 || idx == 4 || idx == 6) ? 191 : 0;
        end
    endtask
    // A new code TOD_NS after each rising edge of the converter's clock; the
    // decoder's calibration has to find where that lands.
    always @(posedge adc_clk) if (rst_n) begin
        // Shift one line late and retain that phase, as at a recording seam
        // or source timing jump. Subsequent lines must not be rejected just
        // because the decoder coasted before the delayed sync arrived.
        stim_n = n - ((n >= 1602*110) ? HSHIFT : 0);
        fsamp = stim_n % 420420;
        pos = ((fsamp * 5) % 8008) / 5;
        half_no = (fsamp * 5) / 4004;
        half_pos = ((fsamp * 5) % 4004) / 5;
        phase = 2.0*PI*n*(315000000.0/88.0)/25200000.0 + 0.73;
        value = 100;
        if (half_no < 18) begin
            if (half_pos < ((half_no >= 6 && half_no < 12) ? 683 : 59))
                value = 100-SYNC_DEPTH;
        end else if (pos < 118) value = 100-SYNC_DEPTH;
        // Continue blanking beyond the equalising/broad-pulse sequence.
        // A nine-line-only VBI cannot catch a 20.5-line burst watchdog bug.
        else if (fsamp < VBI_LINES*8008/5) value = 100;
        else if (pos >= 134 && pos < 197 && !MONO)
            value = 100 - 18*$sin(phase);
        else if (pos >= 237 && pos < 1557) begin
            bar = (pos-237)/165;
            bar_rgb(bar, r, g, b);
            yy = 0.299*r + 0.587*g + 0.114*b;
            uu = 0.493*(b-yy);
            vv = 0.877*(r-yy);
            value = 100 + 90.0/255.0*(yy + (MONO ? 0.0 :
                                                 uu*$sin(phase)+vv*$cos(phase)));
        end
        adc <= #(TOD_NS) $rtoi(value+0.5);
        n = n + 1;
    end
    always @(negedge clk) if (rst_n) begin
        if (vsync_pulse && !recovering) fields = fields + 1;
        if (HSHIFT && n > 1602*111 && n < 1602*125 && !locked)
            $fatal(1, "late sync caused repeated coasting and lost line lock");
        if (!MONO && !recovering && n > 420420 && fsamp < VBI_LINES*8008/5 && !dut.burst_locked)
            $fatal(1, "vertical blanking dropped colour lock");
        if (wr_en) begin
            if (wr_addr[9:0] == 0) pixels = 0; // a partial line may be discarded
            pixels = pixels + 1;
            if (n > 1602*120 && n < 1602*121 && wr_addr[9:0]%80 == 40)
                $display("bar=%0d rgb=%h u=%0d v=%0d ref=%h black=%0d pos=%0d cpos=%0d",
                         wr_addr[9:0]/80,rgb,dut.u_s,dut.v_s,dut.nco_ref,
                         black,pos,dut.cpos);
            if (glitching && fsamp > 1602*30 &&
                (wr_addr[9:0] % 80) >= 32 && (wr_addr[9:0] % 80) < 48) begin
                bar_rgb(wr_addr[9:0]/80, er, eg, eb);
                if ((rgb[23:16] > er ? rgb[23:16] - er : er - rgb[23:16]) > 24 ||
                    (rgb[15:8]  > eg ? rgb[15:8]  - eg : eg - rgb[15:8])  > 24 ||
                    (rgb[7:0]   > eb ? rgb[7:0]   - eb : eb - rgb[7:0])   > 24)
                    glitch_bad = glitch_bad + 1;
            end
            if (!recovering && n > 1602*100 && fsamp > 1602*30 &&
                (wr_addr[9:0] % 80) >= 32 && (wr_addr[9:0] % 80) < 48) begin
                bar_rgb(wr_addr[9:0]/80, er, eg, eb);
                if (MONO) begin
                    er = $rtoi(0.299*er + 0.587*eg + 0.114*eb);
                    eg = er; eb = er;
                end
                if (^rgb === 1'bx) $fatal(1, "unknown RGB");
                err = rgb[23:16]-er; if (err<0) err=-err;
                if (err>max_error) max_error=err;
                if (err>24) bad_colours=bad_colours+1;
                err = rgb[15:8]-eg; if (err<0) err=-err;
                if (err>max_error) max_error=err;
                if (err>24) bad_colours=bad_colours+1;
                err = rgb[7:0]-eb; if (err<0) err=-err;
                if (err>max_error) max_error=err;
                if (err>24) bad_colours=bad_colours+1;
                checks=checks+1;
            end
        end
        if (line_done) begin
            if (glitching) glitch_lines = glitch_lines + 1;
            if (!recovering && n > 1602*100 && pixels != 640) begin
                bad_lines=bad_lines+1;
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

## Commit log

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2026-09-14 Hold colour lock through the vertical interval, and use the measured timing
    burst_age was 15 bits -- 32767 samples, or 20.5 lines -- and the vertical
    interval, which carries no burst, is about 20. The watchdog therefore fired
    once per field by construction, throwing away the lock and the learned
    subcarrier frequency sixty times a second. On the board that left the picture
    in its monochrome fallback for two thirds of the live frames: 17 of 50 in
    colour. Widened to 18 bits, 50 of 50.
    LEGACY_TIMING now defaults on. This source has no sync step, so the run the
    detector qualifies on is the whole blanking interval rather than the sync pulse
    and the standard offsets land in the wrong places --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
2026-09-14 Track the burst angle across lines instead of taking each measurement raw
    The burst angle advances by a nearly constant step from line to line -- 124.8
    degrees on this source, since its subcarrier and line rate are in a fixed ratio
    -- so predicting from the last angle plus a learned step and blending the
    measurement in follows the rotation just as well while averaging the noise.
    Seeded from two measurements, not one: the step is a difference between
    consecutive angles, and deriving it from a single one makes the step the angle
    itself. Shifts evaluated in signed wires, because the accumulator is unsigned
    and an inline >>> would become logical. Split over two clocks, because the
    whole chain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
2026-09-15 Take over the continuation work; retire the hardware A/B as an RTL oracle
    Two real bugs fixed, both caught by tests that now assert:
    - burst_nco held its per-line phase-step prediction across the vertical
    interval, which carries no burst, and arrived at the first returning line
    up to 38 degrees out. A gap longer than five lines now re-learns the step
    instead of extrapolating: sim-tracking goes from 4 failures at 38.22 deg
    worst to none at 4.41 deg.
    - On the standard-timing path a real sync edge arriving just after the
    flywheel had already coasted the line was rejected, so sync never locked:
    sim-capture reported lock_level 38/255 and 89% of lines accepted. Such an
    edge is th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
    [ntsc_video_tb.v]
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2026-09-15 Retract the build-variance claim; disable burst gap handling on this source
    The previous commit's headline finding was wrong and is replaced. Every
    number behind "build-to-build spread is thirty points, so the hardware metric
    cannot resolve an RTL change" was a first-capture-after-programming, which
    reads eight points low while the link and the vertical servo re-acquire. Take
    the second capture and five seeds of one design spread three points, an old
    revision rebuilt reproduces its earlier figure to within two, and the metric
    resolves RTL changes cleanly. The instrument was fine; the protocol was not.
    Measured properly, the regression was entirely burst_nco's gap handling:
    no gap hand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
2026-09-15 Read the ADC back off the HDMI scope, and find where that reading fails
    Continues the scope work: a diagnostic build that starts in the oscilloscope
    view with the full 256-code vertical scale and no UART involved
    (`make ntsc-scope-program`), a recovery script that reads the plotted samples
    by position rather than colour, `.DELETE_ON_ERROR:` so a nextpnr run that
    writes its JSON and then fails timing cannot be packed by the next make, and
    tests for both.
    Two fixes to the recovery, each measured:
    - Detect a mark at r > 120, not r > 180. A mark is one column wide, so where
    neighbouring columns sit at very different heights -- exactly the modulated
    regions worth measuring -- the capture c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
2026-09-15 Trace the banded ADC codes to three stuck-low outputs on the AD9280
    The converter delivers 24 of 256 codes -- nothing between 64 and 127 -- and
    this pins down why. Five independent measurements agree, which matters,
    because each one alone has a failure mode that produced a wrong answer here
    first:
    - the waveform dumped through the HDMI scope;
    - the hardware's own histogram over the UART, bins 4..7 empty, touching no
    part of the display path;
    - a counter on adc_r[6] against a positive control on adc_r[5] that saturates;
    - CLAMP_FORCE, a new parameter that pins AIN to CLAMPIN = 0.625 V, where the
    correct code is 80 and the board returns 17..35;
    - an ohmmeter: 130 kOhm to ground on D2, D3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
2026-09-15 Free-run the scope dump, force the clamp, and record the sync-present result
    Two diagnostic switches, both of which earned their place today:
    - SCOPE_FREERUN arms the dump on its timer instead of waiting for a detected
    line. Without it, a board with no signal shows the buffer's power-up zeros,
    which reads as "every ADC pin is low" and is not a measurement of the pins at
    all. That wasted a test and nearly convicted the wrong part.
    - CLAMP_FORCE holds the analog clamp on, pinning AIN to CLAMPIN = 0.625 V. The
    correct code is 80, which needs bit 6, so it is a known DC input with no room
    to interpret the answer. It is what established that the converter cannot
    represent that bit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
2026-09-15 Choose the luma and chroma gain from the measured span, not from a constant
    Largest measured improvement in this project so far: 50.1% correct rows to
    100.0%, on the same signal, in one change.
    The gains were constants fitted to a source whose blanking-to-white span is 130
    codes. The span grew to 177 -- on its own, along with the sync step that
    appeared during reseating -- and the same constants then map white to 498. The
    bright end folds together, and the bars stop being in luminance order: 50.1%
    correct, 49.9% wrong-order, 55.7% of channel samples saturated.
    What makes this worth writing down is how it presented. Dropped rows were
    0.0% and every frame carried colour, so sync and burst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
2026-09-15 Record the Apicula seed-dependent miscompute bug, and scope the ADC bit question
    YosysHQ/apicula#541: on GW2A-18C, the same RTL produces different functional
    results depending only on nextpnr --seed. Signed comparison is the affected
    construct, and this design is full of them. It is open, has no workaround, and
    does not affect the GW1N-9C the sibling project uses.
    That accounts for the last unexplained thing here: logically identical builds
    measuring 98.4%, 63.8%, 50% and 1.1% correct rows in one session, and hours
    spent hunting an RTL cause that did not exist. Three rules follow -- decide RTL
    in simulation, choose the shipping seed by measurement and record it, and never
    attribute a pic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
2026-09-15 Remove both signed comparisons, the construct Apicula miscompiles here
    YosysHQ/apicula#541 makes signed comparison on GW2A-18C produce different
    answers depending only on the placement seed. The design had two, and both had
    unsigned equivalents:
    - The flywheel's period plausibility test compared period_error against
    +/-P_BAND. It decides whether a sync edge is accepted, so a wrong answer
    corrupts the line timing for a whole frame. Both operands are counts and
    cannot be negative, so the same test is one unsigned magnitude compare,
    registered at the same depth so the two-cycle latency is unchanged.
    period_error stays for the shift that trims period_next; the bug is in
    compariso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
2026-09-15 The stuck ADC bits are the pin choice, not the converter
    A second board with a second AD9280, read with the identical bitstream on the
    same source minutes apart, shows exactly the same three bits dead: 0.00 on bits
    2, 3 and 6 while the other five sit at 0.45..0.67. So the earlier diagnosis
    here -- that U1's output stages were stuck low and the part needed replacing --
    was wrong, and is retracted.
    The evidence behind it was sound as far as it went: a known 0.625 V input whose
    correct code is 80 came back as 17..35. That distinguishes a converter that
    cannot produce the bit from one that can, but not from an FPGA pin that cannot
    receive it. Swapping the part was what settled it.
    adc_d[2]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
2026-09-15 Wire up the ADC out-of-range flag, and find the input over-driving it
    The picture scores 99.97% correct rows and is not finished. The raw trace has
    white, yellow and cyan resting at exactly 179 for 390 consecutive samples --
    0xB3, the largest value expressible with bits 2, 3 and 6 stuck low -- which is
    225 pixels of flat white on screen where three bars should be, and the rest of
    the bars come back washed out.
    The row metric accepts it because it tests for a non-increasing sequence and
    equal bars are non-increasing. A picture can lose its entire bright half and
    still score 99.97%. Noted, with the instruction to read the bar values.
    adc_otr was declared in ntsc_capture and never used. W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
2026-09-15 The top bars merge because of the dead bits, not clipping
    Followed the chain to the end, and the first two readings of it were wrong.
    White, yellow and cyan rest at exactly 179 for 390 consecutive samples, which
    reads as saturation. It is not: with bits 2, 3 and 6 stuck at zero the
    converter maps every true value in 179..191 onto 179, so bars whose real levels
    differ by tens of codes come back identical.
    Two measurements settle it. M5_OUTPUT_LEVEL swept 128, 96, 80 and 64 leaves
    the trace at min=1 max=179 blanking=2 every time -- with 24 expressible codes
    clustered at the ends the observed extremes are pinned regardless of amplitude,
    so levels cannot be measured through this converter at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
2026-09-15 Add the PCB respin instruction document with a measured pin list
    The cause of the three dead ADC bits is the pin choice: adc_d[2], adc_d[3] and
    adc_d[6] land on FPGA pins 42, 41 and 31, which are LCD_R3, LCD_R4 and LCD_B3
    on the Tang Nano 20K and are held low by something on the module. Pin 32
    (LCD_G7) is held high. Pins 27..30 and 77 are also LCD signals and work, so it
    is specific lines rather than the connector, and LCD_INIT0..3 in the schematic
    are the likeliest candidate but are not confirmed.
    Ruled out by measurement and recorded: an open joint, a short to ground, the
    AD9280 itself (a new board with a new part reproduces it), the read-back path,
    the source, the sampling phase, the A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
2026-09-16 Correct the respin pin recommendation: five of them were configuration pins
    The first recommendation put adc_d on pins 54, 55, 56, 61 and 62 because they
    measured free. Reading the FPGA's own pin names off the schematic shows what
    that missed: they are DIN/CLKHOLD_N, SSPI_CS_N/D0, SO/D1, MO/D6 and MI/D7 --
    the SPI configuration interface the part uses at power-up to load its bitstream
    from flash. They measure free because configuration has finished by the time
    anything is measured. An ADC driving them would fight the boot.
    That is the same class of error as the one the document exists to prevent, one
    step further down: a pin was judged by one property without checking the
    others. Caught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
2026-09-16 Move adc_d[2,3,6] to pins that work, and prove one of them on hardware
    The three bits that never arrived were on FPGA pins 42, 41 and 31 -- LCD_R3,
    LCD_R4 and LCD_B3 on the Tang Nano 20K, held low by the module. They move to
    72, 75 and 76, which are plain I/O with no second function, measured free with
    controls, and confirmed against the Apicula chipdb as well as the board
    schematic.
    **One bodge wire settles it.** With only D2 rerouted to pin 72 and the other
    two left on their dead pins, the board reads b2=0.48 where it read 0.00, while
    b3 and b6 stay at 0.00 and every other bit is unchanged. One wire, one bit, the
    one that was moved. That is the end-to-end proof the pull test could not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
2026-09-24 Verify the respun board: all eight ADC bits live; default to standard sync geometry
    The corrected carrier (adc_d[2,3,6] on FPGA 72/76/75) reads 79 distinct
    codes where the old pins gave 18, with bits 2/3/6 at 0.64/0.33/0.48
    instead of 0.00.
    With eight working bits the M5 source shows a 33-code sync step, so the
    "no sync amplitude" reading and the legacy geometry built on it were
    artefacts of the dead bits. Back to back at seed 3 the standard geometry
    drops 0.43% of rows against 47.8% and carries colour on 120 frames of
    120 against 0, so LEGACY_TIMING now defaults to 0 and the M5 set moves to
    make ntsc-legacy.
    Records the remaining defect: the back porch reads 16 codes low on
    alternate lin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
2026-09-25 Decode the M5 correctly on the respun board: calibrate the ADC read instant
    The colour that came and went between rebuilds of identical RTL was the ADC
    read instant. One of five 126 MHz reads per conversion is used, and which
    one is safe depends on the fabric round trip, so a fixed phase landed in the
    converter's switching window in some placements. Flat areas still decoded
    and the burst was corrupted on every line. AUTO_PHASE counts, per read
    phase, how often the data changes, and reads at the quietest point. Two
    placements now agree with the replay and the floating-point reference.
    Found by recording the source at full rate: a TAPE build shows 32768 raw
    samples as grey cells on HDMI,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
2026-09-25 Survive the M5's boot-dependent blanking; move the ADC interface into IO logic
    The M5 was power-cycled while C13 was fitted and came back with different
    junk in its two DMA line buffers: the front porch now alternates 99/115,
    so the front-porch black reference banded again. In both recorded boots
    one porch is true blanking on every line and the other sits at the
    burst's low level, so black is now max(front porch, back porch) at
    quarter weight across lines. Both recordings replay without banding;
    on the board the white bar moves 0.8..1.2 codes line to line.
    adc_d is captured by IDDR and adc_clk driven by ODDR, so the converter
    round trip no longer depends on routing. That did not end the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
2026-09-25 Prepare the input-filter measurement; tape levels survive range expansion
    The capture card began expanding limited range after a replug, which merged
    the tape's nibble levels 0/1 and 14/15. Tape grey is now 16 + 14 x nibble,
    inside limited range either way; sim-tape passes with the new levels.
    scripts/filter_check.py fits burst and bars at the subcarrier and at both
    alias frequencies (25.2 - 6 fsc, 8 fsc - 25.2) across two TAPE recordings and
    reports what an input filter bought and the chroma gain it cost.
    sim/m5_tape_base_18lines.hex is the before recording, on the M5 boot that
    must stay powered through the rework.
    CLAUDE.md: why the crawl cannot be removed digitally, the planned LC filt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
2026-09-25 burst_nco: act on the gate's fall by clock count, so one sample a clock works
    The last burst product reaches sum_r three clocks after the gate falls. At
    five clocks per sample that had always happened by the next strobe; at one
    sample per clock it has not. The fall is now acted on three clocks after it
    is seen, adding only this clock's step to the phase, and a gate restart also
    drops what is still in the pipeline.
    Gapped operation is unchanged: reference worst 4.36/4.89/7.45 deg, tracking
    4.41, sim-burst wobble 2.08. burst_products_tb checks the correlation after
    the flush instead of on the strobe.
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2026-09-25 Run the whole decoder on the pixel clock, one sample per clock, with no ALUs
    126 MHz now reaches only the converter's clock (adc_front's ODDR); every
    other register is on the 25.2 MHz pixel clock, and the design is built with
    synth_gowin -noalu: 0 ALU cells (Apicula #514), 58% of LUTs, 55.6 MHz
    against 25.2 needed.
    What one sample per clock needed, each decided by a bench:
    - burst_nco's correlator weights come straight from the current phase. A
    registered weight lagged the phase by a clock: invisible at five clocks per
    sample, 51 degrees of hue at one (sim-video failed with max_error 216).
    - The period arithmetic is registered one sample ahead (rcnt + 1); the
    window compares against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
    [ntsc_video_tb.v]
2026-09-25 CLAUDE.md: the crawl can be combed out over five lines, on a still pattern
    The note said the alias products cannot be removed digitally. Five lines are
    8008 samples, a whole number, over which chroma inverts and both products
    repeat; (x[n] - x[n-8008])/2 on the three M5 recordings leaves chroma
    unchanged and cuts the aliases by 14..19 dB. It only holds for a picture that
    repeats every five lines and for clocks matched to a few ppm, so the analogue
    filter remains the fix; recorded so the option is not rediscovered or wrongly
    ruled out.
2026-09-25 Calibrate on the clean bits; show the converter's state in the picture
    Measured per bit on the board (make ntsc-adcdiag): bits 2, 3, 6, 7 (pins 72,
    76, 75, 77) read alike on both edges at four rotations of ten; bits 0, 1, 4, 5
    (pins 27..30, beside the HDMI pins) disagree on 3..13% of conversions at
    every rotation. Counting them, the calibration never found a quiet rotation
    and re-swept for ever. CAL_MASK counts the top bank only: every seed now
    settles once, at rotation 3, with 0 disagreements in 16384.
    The bottom eight rows carry adc_front's state (ADC_STRIP), read with
    scripts/adc_strip.py; scripts/adc_diag.py tabulates the diagnostic build.
    Also: a constant async reset for rot, and sim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
2026-09-25 Pack ADC bits 0, 1, 4, 5 as LVCMOS33, not as LVDS receivers; escape the tracker's trap
    Not the circuit. Apicula's gowin_pack configures every input buffer with its
    bank's IO_TYPE, and forces a bank holding a true LVDS output to LVDS25.
    Bank 5 holds the HDMI clock lane and ADC pins 27..30, so bits 0, 1, 4 and 5
    were packed as LVDS receivers, each pin pair compared against the other.
    A raw recording of both IDDR reads of all eight bits at 126 MHz showed it:
    the bank-1 bits clean at one read position of ten, the bank-5 bits flipping
    all over the conversion, 1400 isolated glitches in 32768 reads, and the
    errors where a pair's bits were equal (3.25 wrong reads of ten for bit 0 when
    bits 0 and 1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
2026-09-25 Escape the burst tracker's trap; choose the read by all eight bits
    The colour failures that followed neither placement nor the ADC read were the
    burst tracker. A learned per-line step a half or a third of a turn wrong is
    a stable trap: the prediction cycles round the measurement and the
    corrections cancel. Whether an acquisition falls in is chance, so the same
    bitstream decoded colour on one load and not the next. The strip showed it:
    the CORDIC's angle matched atan2 of its own inputs within 0.2 deg on every
    frame, good and bad, while burst_off cycled through two or three values.
    burst_nco keeps a running mean of the tracking miss and relearns the step when
    it passes 45 deg. sim-trackin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
2026-09-26 Keep the known-good bitstream of 2026-09-26 and a way back to it
    bitstreams/ntsc_good_2026-09-26.fs.gz is the build of good-2026-09-26
    (8ea8dc7) -- rebuilt from that tag, sha256 of the .fs 07ca2c89...acc --
    the version flashed and verified across a power cycle. make restore-flash
    writes it back, make restore-program loads it to SRAM; checked on the board:
    rotation 0.5 deg, colour on 60/60 frames. The README (Japanese) now covers
    flashing, restoring, and the noise display for a broken input.
2026-09-26 Take each line's burst angle raw; fix the tracker's prediction; seed 5
    The remaining horizontal bands -- every bar of a line turning hue together,
    36 degrees rms, dying away over 4..20 lines -- were made on the board: the
    recording's burst varies 1.0 degree rms line to line and the replay holds
    every active line within 2, across a burstless vertical interval too.
    - burst_nco: BURST_TRACK now defaults to 0. With eight working bits a
    line's measurement is good to a degree, so averaging buys nothing and
    the tracker's memory lets one bad update spoil twenty lines.
    - burst_nco: the tracker's prediction now includes correlation_adjust, the
    phase step the loop has just given the oscillator.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
2026-09-26 Glitch controls: the 8Angle's knobs break the decoder's own stages
    Each knob breaks one stage of the decoder rather than processing its
    picture: the sync slicer (dark picture read as sync), horizontal hold (real
    syncs dropped, flywheel detuned), vertical hold (the frame servo's target
    walks), the subcarrier reference (a phase ramp the burst correction cannot
    see), Y/C separation (luma opened to the subcarrier), the converter clock
    (off its calibrated phase, into the switching window), the black reference
    (measured inside the picture) and the line store (lines left unpublished).
    Fully left is off; the switch enables them; nothing acts without the unit.
    KNOB_INVERT is 1 by measurement: fully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
    [ntsc_video_tb.v]
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2026-09-27 Glitch knobs, second round: stretch, colour, TMDS error, wrapping matrix
    From the bench's trial of the first set:
    - knob 3 (vertical roll) only scrolled -- the frame servo may move one line
    a frame or the sink drops the link -- and knob 4 overlapped the burst gate:
    knob 3 is now a random per-line resampling rate (lines squeezed into the
    left half or stretched to twice their width), knob 4 the burst gate slid
    into the picture together with the reference ramp;
    - knob 5 (Y/C blend) was too gentle to see: it is now a TMDS bit error. Done
    on the wire, even with control tokens left alone, it made this sink drop
    the picture; it is now worked out in the pixel domain as the sink would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
2026-09-27 Follow a 240p source: a 524-line frame when fields are 262 lines
    Game consoles send 262 lines every field (60.05 Hz), which wants a
    523.9-line output frame; 525 left the servo 1.13 lines a frame short and
    the picture crept up the screen. The capture now reports the clocks
    between field events, and the frame's base length is 524 or 525 from the
    last two fields' sum, switched only once two plausible pairs agree.
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2026-10-03 Carrier board v0.2: AIN bias, chip parts, ground vias, edge clearance
    Design files only; v0.2 has not been manufactured. The board as built is
    tag v0.1, and hardware/jlcpcb/ still holds v0.1's production files.
    - R2 22k -> 10k and a new R19, 47k from AIN to CLAMPIN: AIN gets a DC
    path, and CLAMPIN is 1.0 V instead of 0.625.
    - C13 is an 0603 in place of the leaded disc under the module.
    - FB1 and FB2 are 0805 chip beads (LCSC C1017, a JLCPCB Basic part).
    The leaded parts doubled as jumpers, so the GND link under FB1 is
    0.6 mm wide there and vias stand where the four holes were.
    - GND vias beside U1's ground pins 1, 14 and 16..18.
    - The top-edge GND track is 0.69 mm from the edge (was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
    [tangADC.kicad_pcb, tangADC.kicad_sch]
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2026-10-03 Board v0.2: ground pads join the pour solidly; Gerbers regenerated
    Both GND zones use thermal reliefs for through-hole pads only, so the
    surface-mount ground pads -- U1's AVSS and DRVSS among them -- connect
    to the pour without spokes. DRC's starved-thermal errors go from six
    to one (J2 pin 2, a through-hole that reaches the B.Cu pour anyway).
    Only the top copper layer of the Gerber set changes. U1 is soldered by
    hand, and its ground pins now sink more heat; docs/pcb-respin.md 4.1
    says so.
    [tangADC.kicad_pcb]
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
